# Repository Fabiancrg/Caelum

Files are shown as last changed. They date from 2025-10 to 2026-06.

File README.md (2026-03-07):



| Supported Target | ESP32-H2 |
| --- | --- |

# Caelum - Zigbee Weather Station




## Project Description

This project implements a battery-powered comprehensive weather station using ESP32-H2 with Zigbee connectivity. The device operates as a Zigbee Sleepy End Device (SED) with automatic light sleep for ultra-low power consumption while maintaining network responsiveness.

**Hardware v2.0** features dual I2C buses supporting multiple sensor combinations, dedicated rain gauge and anemometer inputs, DS18B20 temperature sensor, light sensor, and wind direction sensor for professional weather monitoring capabilities.

## Device Features

### 🌐 Zigbee Endpoints Overview (v2.0 Hardware)

| Endpoint | Device Type | Clusters | Description |
|---|---|---|---|
| **1** | Environmental Sensor | Temperature, Humidity, Pressure, Battery, OTA | Multi-sensor support via dual I2C buses |
| **2** | Rain Gauge | Analog Input | Tipping bucket rain sensor with rainfall totals (GPIO12) |
| **3** | DS18B20 Temperature | Temperature Measurement | External waterproof temperature probe (GPIO24) |
| **4** | Anemometer (Wind Speed) | Analog Input | Wind speed sensor with pulse counting (GPIO14) |
| **5** | Wind Direction | Analog Input | AS5600 magnetic wind vane (I2C Bus 2) |
| **6** | Light Sensor | Illuminance Measurement | VEML7700 ambient light sensor (I2C Bus 2) |

### 💡 LED Boot Indicator (Always Active)

The device includes a WS2812 RGB LED on GPIO8 (ESP32-H2) that provides visual feedback during boot and network join:
- **Yellow (Blinking)**: Joining/searching for network  
- **Blue (Steady, 5 seconds)**: Successfully connected to Zigbee network
- **Red (Blinking, 10 times)**: Connection failed after max retries
- **Off**: LED powered down after boot sequence (RMT peripheral disabled for power savings)

**Power Optimization**: The LED and its RMT peripheral are permanently disabled after the initial boot/join sequence to save ~1-2mA. This is critical for achieving 0.68mA sleep current. The LED cannot be re-enabled remotely - it only operates during the first boot cycle.

### 📋 Detailed Endpoint Descriptions (v2.0)

#### **Endpoint 1: Environmental Monitoring & Power Management**
- **I2C Bus 1 (GPIO10/11)**: Temperature, Humidity, Pressure sensors
- **Supported Sensors** (automatically detected):
  - **SHT41** (Bus 1): High-accuracy Temperature + Humidity (±0.2°C, ±1.8% RH)
  - **AHT20** (Bus 1): Alternative Temperature + Humidity sensor
  - **BMP280** (Bus 1): Temperature + Pressure (±1 hPa accuracy)
  - **BME280** (Bus 1): All-in-one Temperature + Humidity + Pressure
  - **DPS368** (Bus 1): High-precision Pressure sensor (±0.002 hPa)
- **Measurements**: 
  - 🌡️ **Temperature**: -40°C to +85°C (multiple sources available)
  - 💧 **Humidity**: 0-100% RH (from SHT41/AHT20/BME280)
  - 🌪️ **Pressure**: 300-1100 hPa (from BMP280/BME280/DPS368)
  - 🔋 **Battery Monitoring**: Li-Ion voltage (2.7V-4.2V) and percentage
- **Battery Monitoring**:
  - **Hardware**: GPIO4 (ADC1_CH4) with voltage divider
  - **MOSFET Control**: GPIO3 for active power management
  - **Voltage**: Real-time battery voltage in 0.1V units
  - **Percentage**: Battery level 0-100% based on Li-Ion discharge curve
  - **Calibration**: ESP32-H2 ADC correction factor (1.604x) for accurate readings
  - **Optimized Reading**: Time-based hourly intervals with NVS persistence

#### **Endpoint 2: Rain Gauge System**
- **Hardware**: Tipping bucket rain gauge with reed switch
  - **ESP32-H2 v2.0**: GPIO12 (interrupt-capable, dedicated rain input)
- **Measurements**: Cumulative rainfall in millimeters (0.36mm per tip)
- **Features**: 
  - Interrupt-based detection (200ms debounce)
  - Persistent storage (NVS) for total tracking
  - Smart reporting (1mm threshold increments)
  - Network-aware operation (ISR enabled only when connected)
  - Works during light sleep - wakes device on rain detection
- **Specifications**: 
  - Maximum rate: 200mm/hour supported
  - Accuracy: ±0.36mm per bucket tip
  - Storage: Non-volatile total persistence across reboots
- **Use Case**: Weather station, irrigation control, flood monitoring

#### **Endpoint 3: DS18B20 External Temperature Sensor**
- **Hardware**: DS18B20 1-Wire waterproof temperature probe
  - **GPIO24**: 1-Wire bus with parasitic power support
- **Measurements**: External temperature -55°C to +125°C (±0.5°C accuracy)
- **Features**:
  - Waterproof probe for outdoor/liquid temperature monitoring
  - 12-bit resolution (0.0625°C precision)
  - Independent from I2C environmental sensors
  - Parasitic power mode (no external power needed)
- **Use Case**: Soil temperature, water temperature, outdoor ambient temperature

#### **Endpoint 4: Anemometer (Wind Speed)**
- **Hardware**: Pulse-output anemometer
  - **GPIO14**: Interrupt-capable input for pulse counting
- **Measurements**: Wind speed via pulse frequency
- **Features**:
  - Interrupt-based pulse counting with debounce
  - Persistent storage (NVS) for total tracking
  - Similar architecture to rain gauge (proven reliability)
    
#### **Endpoint 5: Wind Direction**
- **Hardware**: AS5600 magnetic rotary position sensor (I2C Bus 2)
  - **I2C Address**: 0x36 (fixed)
  - **Resolution**: 12-bit (0.087° per step)
- **Measurements**: Wind direction 0-360° (compass bearing)
- **Features**:
  - Contactless magnetic sensing (no wear)
  - Absolute position (no homing required)
  - High resolution for accurate wind vane reading

#### **Endpoint 6: Light Sensor**
- **Hardware**: VEML7700 ambient light sensor (I2C Bus 2)
  - **I2C Address**: 0x10 (fixed)
  - **Range**: 0.0036 to 120,000 lux
- **Measurements**: Ambient light intensity in lux
- **Features**:
  - High dynamic range (16-bit resolution)
  - Automatic gain adjustment
  - Human eye response matching

### 🔧 Hardware Configuration

#### **Required Components (v2.0 Hardware)**
- ESP32-H2 development board (RISC-V architecture)
- **I2C Bus 1 Sensors** (Temperature/Humidity/Pressure):
  - **SHT41** - High-accuracy temperature + humidity (recommended)
  - **AHT20** - Alternative temperature + humidity sensor
  - **BMP280** - Pressure sensor (pairs with SHT41/AHT20)
  - **BME280** - All-in-one temp/humidity/pressure (alternative)
  - **DPS368** - High-precision barometric pressure sensor (optional, alternative to BMP280)
- **I2C Bus 2 Sensors** (Wind/Light/Pressure):
  - **AS5600** - Magnetic rotary position sensor for wind direction
  - **VEML7700** - Ambient light sensor (lux measurements)
- **1-Wire Sensor**:
  - **DS18B20** - Waterproof temperature probe for external measurements
- **Weather Sensors**:
  - Tipping bucket rain gauge with reed switch (0.36mm per tip)
  - Anemometer with pulse output for wind speed measurement
- **Power System**:
  - Li-Ion battery
  - Voltage divider
  - MOSFET for battery power management (GPIO3 control)
- Zigbee coordinator (ESP32-H2 or commercial gateway)

#### **Pin Assignments**

**ESP32-H2 (v2.0 Hardware)**
```
GPIO 1  - I2C Bus 2 SDA (AS5600 wind direction, VEML7700 light sensor, DPS368 pressure)
GPIO 2  - I2C Bus 2 SCL (AS5600 wind direction, VEML7700 light sensor, DPS368 pressure)
GPIO 3  - Battery MOSFET control (active power management)
GPIO 4  - Battery voltage input (ADC1_CH4 with voltage divider)
GPIO 8  - WS2812 RGB LED (debug indicator, optional)
GPIO 9  - Built-in button (factory reset)
GPIO 10 - I2C Bus 1 SDA (SHT41/AHT20 temp/humidity, BMP280/BME280 pressure)
GPIO 11 - I2C Bus 1 SCL (SHT41/AHT20 temp/humidity, BMP280/BME280 pressure)
GPIO 12 - Rain gauge input (tipping bucket with reed switch)
GPIO 14 - Anemometer input (wind speed pulse counter)
GPIO 24 - DS18B20 1-Wire temperature sensor (waterproof probe)
```

**Note**: v2.0 uses dedicated dual I2C buses to avoid address conflicts and support expanded sensor array.

### 🔌 Zigbee Integration
- **Protocol**: Zigbee 3.0  
- **Device Type**: Sleepy End Device (SED) - maintains network connection while sleeping
- **Sleep Mode**: Automatic light sleep with 7.5s keep-alive polling
- **Sleep Threshold**: 6.0 seconds (allows sleep between keep-alive polls)
- **Supported Channels**: 11-26 (2.4 GHz)
- **Compatible**: Zigbee2MQTT, Home Assistant ZHA, Hubitat
- **OTA Support**: Over-the-air firmware updates enabled (see [OTA_GUIDE.md](OTA_GUIDE.md))

### ⚡ Power Management (Light Sleep Mode)

**Zigbee Sleepy End Device (SED) Configuration**:
- **Keep-alive Polling**: 7.5 seconds (maintains parent connection)
- **Sleep Threshold**: 6.0 seconds (enters light sleep when idle)
- **Parent Timeout**: 64 minutes (how long parent keeps device in child table)
- **RX on When Idle**: Disabled (radio off during sleep for power savings)

**Power Consumption**:
- **Sleep Current**: **0.68mA** (with RMT peripheral powered down)
- **Transmit Current**: 12mA during active transmission
- **Average Current**: ~0.83mA (includes 7.5s polling cycles)
- **LED Power-down**: Critical for low power - RMT peripheral disabled after boot

**Sleep Behavior**:
- Device sleeps automatically when Zigbee stack is idle (no activity for 6 seconds)
- Wakes every 7.5 seconds to poll parent for pending messages
- Rain detection wakes device instantly via GPIO interrupt
- Quick response to Zigbee commands (<10 seconds typical)

**Power Optimization Features**:
- RMT peripheral (LED driver) powered down after boot sequence (~1-2mA savings)
- Light sleep maintains Zigbee network association (no rejoin delays)
- Automatic sleep/wake managed by ESP Zigbee stack
- Battery monitoring on 1-hour intervals with NVS persistence
- BME280 forced measurement mode (sensor sleeps between readings)

**Battery Life Estimate**:
- **2500mAh Li-Ion**: ~125 days (4+ months) at 0.83mA average
- **Breakdown**: 
  - ~7.4 seconds sleep per 7.5 second cycle (0.68mA)
  - ~0.1 seconds active per cycle (12mA transmit)
  - Sensor readings and reports as configured

**OTA Behavior**: 
- Device stays awake during firmware updates (`esp_zb_ota_is_active()` check)
- Normal sleep resumes after OTA completion

### � Zigbee Integration
- **Protocol**: Zigbee 3.0  
- **Device Type**: End Device (sleepy end device for battery operation)
- **Supported Channels**: 11-26 (2.4 GHz)
- **Compatible**: Zigbee2MQTT, Home Assistant ZHA
- **OTA Support**: Over-the-air firmware updates enabled (see [OTA_GUIDE.md](OTA_GUIDE.md))

## 🚀 Quick Start

### Prerequisites

```bash
# Install ESP-IDF v5.5.3 or later
git clone -b v5.5.3 --recursive https://github.com/espressif/esp-idf.git
cd esp-idf
# For ESP32-H2 (v2.0 hardware required)
./install.sh esp32h2
. ./export.sh
```

### Configure the Project
```bash
# For ESP32-H2 v2.0 hardware
idf.py set-target esp32h2
idf.py menuconfig
```

**Note**: v2.0 firmware requires v2.0 hardware (dual I2C buses, new GPIO assignments). For v1.0 hardware (ESP32-C6 or ESP32-H2 single I2C), use the `caelum-weatherstation` repository.

### Build and Flash
```bash
# Erase previous data (recommended for first flash)
idf.py -p [PORT] erase-flash

# Build and flash the project
idf.py -p [PORT] flash monitor
```

### 🛠️ Configuration

### Device Operation

#### **Factory Reset**
- **Built-in Button (GPIO 9)**:
  - Long press (5s): Factory reset device and rejoin network

#### **Automatic Features**
- **Light Sleep**: Automatic entry when idle (6s threshold, 7.5s keep-alive polling)
- **Sensor Reporting**: Environmental data reported after network join and on-demand
- **Rain Detection**: Interrupt-based instant wake and reporting (1mm threshold)
- **Battery Monitoring**: Hourly readings with time-based NVS persistence
- **Network Status**: Visual feedback via RGB LED during boot/join only
- **Power Savings**: RMT peripheral powered down after boot (~1-2mA savings)

### 📡 Data Reporting
- **Temperature/Humidity/Pressure**: Reported after network join and as configured
- **Rainfall**: Immediate on rain detection (1mm threshold)
- **Battery**: Hourly time-based readings with NVS persistence
- **Reporting Interval**: Configurable 60-7200 seconds via Endpoint 3
- **Response Time**: <10 seconds for Zigbee commands (7.5s keep-alive polling)

## 📊 Example Output

### Device Initialization (with Sensor Auto-Detection)
```
I (3668) i2c_bus: i2c0 bus inited
I (3670) i2c_bus: I2C Bus V2 Config Succeed, Version: 1.5.0
I (3686) i2c_bus: found i2c device address = 0x44
I (3695) i2c_bus: found i2c device address = 0x76
I (3696) SENSOR_IF: I2C scan: 2 device(s): 0x44 0x76
I (3697) SENSOR_IF: Probing for BME280...
W (3698) BME280_APP: ⚠ Detected BMP280 sensor (Chip ID: 0x58) - Temperature + Pressure ONLY (no humidity!)
I (3704) SENSOR_IF: BMP280 detected (no humidity), searching for separate humidity sensor...
I (3710) SHT41: sht41_init: device created successfully
I (3715) SENSOR_IF: Detected sensor combo: SHT41 + BMP280 (temp/RH from SHT41, pressure from BMP280)
I (3720) WEATHER_STATION: Detected SHT41 + BMP280 sensor combo on ESP32-H2 (SDA:GPIO10, SCL:GPIO11)
I (3730) RAIN_GAUGE: Rain gauge initialized. Current total: 0.00 mm
```

### Alternative Sensor Configurations
```
# BME280 all-in-one sensor
I (3697) SENSOR_IF: Probing for BME280...
I (3698) BME280_APP: ✓ Detected BME280 sensor (Chip ID: 0x60) - Temperature + Humidity + Pressure
I (3704) SENSOR_IF: Detected sensor: BME280
I (3710) WEATHER_STATION: Detected BME280 sensor on ESP32-H2 (SDA:GPIO10, SCL:GPIO11)

# SHT41 alone (no pressure sensor)
I (3697) SENSOR_IF: Probing for BME280...
I (3698) SENSOR_IF: BME280 not found, probing for SHT41 + BMP280 combo...
I (3704) SHT41: sht41_init: device created successfully
I (3710) SENSOR_IF: Detected sensor: SHT41 only (pressure will default to 1000.0 hPa)
I (3715) WEATHER_STATION: Detected SHT41 sensor on ESP32-H2 (SDA:GPIO10, SCL:GPIO11)
```

### Zigbee SED Configuration
```
I (600) WEATHER_STATION: 🔋 Configured as Sleepy End Device (SED) - rx_on_when_idle=false
I (610) WEATHER_STATION: 📡 Keep-alive poll interval: 7500 ms (7.5 sec)
I (620) WEATHER_STATION: 💤 Sleep threshold: 6000 ms (6.0 sec) - production optimized
I (630) WEATHER_STATION: ⏱️  Parent timeout: 64 minutes
I (640) WEATHER_STATION: ⚡ Power profile: 0.68mA sleep, 12mA transmit, ~0.83mA average
```

### Network Connection (LED Shows Status)
```
I (3558) WEATHER_STATION: Joined network successfully (Extended PAN ID: 74:4d:bd:ff:fe:63:f7:30, PAN ID: 0x13af, Channel:13, Short Address: 0x7c16)
I (3568) WEATHER_STATION: 💡 LED will power down in 5 seconds to save battery
I (3578) RAIN_GAUGE: Rain gauge enabled - device connected to Zigbee network
I (3588) WEATHER_STATION: 📊 Scheduling initial sensor data reporting after network join
I (8568) WEATHER_STATION: 🔌 RGB LED RMT peripheral powered down (boot sequence complete)
```

### Sensor Data Reporting
```
I (4000) WEATHER_STATION: 🌡️ Temperature: 22.35°C reported to Zigbee  
I (5010) WEATHER_STATION: 💧 Humidity: 45.20% reported to Zigbee
I (6020) WEATHER_STATION: 🌪️ Pressure: 1013.25 hPa reported to Zigbee
I (7030) BATTERY: 🔋 Li-Ion Battery: 4.17V (98%) - Zigbee values: 41 (0.1V), 196 (%*2)
I (8040) WEATHER_STATION: 📡 Temp: 22.4°C
I (8050) WEATHER_STATION: 📡 Humidity: 45.2%
I (8060) WEATHER_STATION: 📡 Pressure: 1013.3 hPa
```

### Rain Gauge Activity
```  
I (10000) RAIN_GAUGE: 🌧️ Rain pulse #1: 0.36 mm total (+0.36 mm)
I (10020) RAIN_GAUGE: ✅ Rain reported: 0.36 mm
I (10030) WEATHER_STATION: 📡 Rain: 0.36 mm
```

### Light Sleep Activity
```
I (15000) WEATHER_STATION: Zigbee can sleep
I (15010) WEATHER_STATION: 💤 Entering light sleep (will wake for 7.5s keep-alive poll)
```

## 🏠 Home Assistant Integration

When connected to Zigbee2MQTT or other Zigbee coordinators, the v2.0 device exposes:

- **6x Sensor entities**: 
  - Temperature (Environmental + DS18B20 external probe)
  - Humidity
  - Pressure  
  - Battery Percentage
  - Wind Speed
  - Wind Direction (0-360° compass bearing)
  - Light Level (lux)
- **2x Sensor entities**: 
  - Battery Voltage (mV)
  - Rainfall total (mm) with automatic updates
- **LED Control**: ⚠️ **Not available in v2.0** - LED operates only during boot/join sequence

### Endpoint Summary for Home Assistant

| Endpoint | Entity Type | Measurements | Update Frequency |
|---|---|---|---|
| 1 | Sensor | Temp, Humidity, Pressure, Battery | Configurable (default 15min) |
| 2 | Sensor | Rainfall total (mm) | On rain detection (1mm threshold) |
| 3 | Sensor | External temperature (DS18B20) | Configurable (default 15min) |
| 4 | Sensor | Wind speed | Configurable (default 15min) |
| 5 | Sensor | Wind direction (0-360°) | Configurable (default 15min) |
| 6 | Sensor | Light level (lux) | Configurable (default 15min) |

### Zigbee2MQTT Integration

A custom external converter is provided for full feature support with Zigbee2MQTT. See [ZIGBEE2MQTT_CONVERTER.md](ZIGBEE2MQTT_CONVERTER.md) for:
- Converter installation instructions
- Multi-endpoint support configuration
- v2.0 endpoint mappings (6 endpoints)
- Home Assistant automation examples

**Note**: v2.0 requires updated converter due to new endpoint structure (6 endpoints vs 4 in v1.0)

## 🔄 Migration Guide: v1.0 → v2.0

### Hardware Requirements
⚠️ **v2.0 firmware requires v2.0 hardware** - GPIO assignments are completely different.

| Component | v1.0 | v2.0 | Compatible? |
|---|---|---|---|
| Target | ESP32-H2 or C6 | ESP32-H2 only | ❌ Different GPIO |
| I2C Bus | Single (GPIO10/11) | Dual (GPIO10/11 + GPIO1/2) | ⚠️ Partial |
| Rain Gauge | GPIO12 (H2), GPIO5 (C6) | GPIO12 only | ✅ H2 compatible |
| Pulse Counter | GPIO13 | Removed | ❌ Deprecated |
| Anemometer | N/A | GPIO14 | ➕ New |
| DS18B20 | N/A | GPIO24 | ➕ New |
| Battery MOSFET | N/A | GPIO3 | ➕ New |

## 🔄 OTA Updates

This project supports Over-The-Air (OTA) firmware updates via Zigbee network. See [OTA_GUIDE.md](OTA_GUIDE.md) for detailed instructions on:
- Creating OTA images
- Configuring Zigbee2MQTT for OTA
- Performing updates
- Troubleshooting OTA issues

## 📄 License

This project follows dual licensing:
- **Software**: GNU General Public License v3.0 (see [LICENSE](LICENSE))
- **Hardware**: Creative Commons Attribution-NonCommercial-ShareAlike 4.0 (see [LICENSE-hardware](LICENSE-hardware))

## 🤝 Contributing

Contributions are welcome! Please feel free to submit issues or pull requests.

For technical queries, please open an issue on GitHub. Include:
- Complete serial monitor output
- Hardware configuration details  
- ESP-IDF and SDK versions
- Specific symptoms and reproduction steps

## 💖 Support

If you find this project useful, consider supporting the development:



---

**Project**: Caelum - ESP32 Zigbee Weather Station  
**Version**: v2.0 - Hardware redesign with dual I2C buses and expanded sensor array  
**Compatible**: ESP32-H2 (v2.0), ESP32-C6 (v1.0 legacy), ESP-IDF v5.5.3+  
**License**: GPL v3 (Software) / CC BY-NC-SA 4.0 (Hardware)  
**Features**: 
- 6-endpoint design (ENV, RAIN, DS18B20, WIND_SPEED, WIND_DIR, LIGHT)
- Dual I2C buses for expanded sensor support without address conflicts
- Professional weather monitoring (temperature, humidity, pressure, rain, wind, light)
- DS18B20 waterproof external temperature probe
- AS5600 magnetic wind direction sensor (0-360°)
- VEML7700 ambient light sensor (0.0036-120k lux)
- Anemometer wind speed measurement
- OTA firmware updates
- Optimized battery monitoring with hourly time-based intervals
- WS2812 RGB LED status indicator during boot/join
- Ultra-low power: 0.68mA sleep current for extended battery life

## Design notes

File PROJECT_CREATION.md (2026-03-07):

# WeatherStation Project Creation Summary

## Overview
Successfully created a new **WeatherStation** project based on the **ZigbeeMultiSensor** project.

## Project Location
```
c:\Devel\Repositories\WeatherStation
```

## What Was Done

### 1. Project Structure Copied
All essential files and directories were copied from ZigbeeMultiSensor:
- ✅ Source code (`main/` directory with all .c and .h files)
- ✅ Build configuration (`CMakeLists.txt`, `sdkconfig`, `sdkconfig.defaults`)
- ✅ Development tools (`.vscode/`, `.devcontainer/`, `.clangd`)
- ✅ Project metadata (`.gitignore`, `partitions.csv`)

### 2. Excluded Items (Clean Copy)
The following were intentionally excluded:
- ❌ `.git/` - No git history (fresh start)
- ❌ `build/` - Build artifacts (will be regenerated)
- ❌ `managed_components/` - Will be downloaded on first build
- ❌ `dependencies.lock` - Will be regenerated
- ❌ Build logs and temporary files

### 3. Project Renamed
- **CMakeLists.txt**: Project name changed from `zigbeeTest` to `WeatherStation`
- **README.md**: Completely rewritten for weather station focus

## Project Features (Inherited from ZigbeeMultiSensor)

### Hardware Support
- **MCU**: ESP32-C6 or ESP32-H2
- **Zigbee**: Full Zigbee 3.0 stack with 5 endpoints

### Endpoints Configuration
1. **Endpoint 1**: LED Strip (WS2812B on GPIO 8)
2. **Endpoint 2**: GPIO LED (GPIO 0)
3. **Endpoint 3**: Button Sensor (GPIO 12)
4. **Endpoint 4**: BME280 Environmental Sensor (I2C on GPIO 6/7)
5. **Endpoint 5**: Rain Gauge (GPIO 18)

### Source Files Included
```
main/
├── bme280_app.c         # BME280 sensor driver
├── bme280_app.h         # BME280 interface
├── esp_zb_light.c       # Main Zigbee stack (49KB)
├── esp_zb_light.h       # Configuration headers
├── light_driver.c       # LED/GPIO control (19KB)
├── light_driver.h       # Driver interface
├── CMakeLists.txt       # Component config
└── idf_component.yml    # Dependencies
```

## Next Steps

### 1. Initialize Git (Optional)
```bash
cd c:\Devel\Repositories\WeatherStation
git init
git add .
git commit -m "Initial commit - Weather Station project based on ZigbeeMultiSensor"
```

### 2. Build the Project
```bash
cd c:\Devel\Repositories\WeatherStation

# Set target (if not already set)
idf.py set-target esp32c6

# Build
idf.py build
```

### 3. Flash to Device
```bash
# Erase flash (recommended for first flash)
idf.py erase-flash

# Flash and monitor
idf.py -p COM_PORT flash monitor
```

### 4. Customization Ideas
Consider modifying for weather station specific features:
- Add weather trend calculation (pressure changes)
- Implement data logging to flash
- Add wind speed/direction sensors
- Customize LED patterns for weather alerts
- Add battery monitoring for solar power

## Configuration Files

### Key Settings in `sdkconfig`
- Zigbee role: End Device (can be changed to Router)
- I2C configuration for BME280
- GPIO assignments for sensors and LEDs

### Component Dependencies (`main/idf_component.yml`)
- LED strip driver
- BME280 sensor library
- ESP-Zigbee libraries

## Differences from Original

| Aspect | ZigbeeMultiSensor | WeatherStation |
|---|---|---|
| Project Name | `zigbeeTest` | `WeatherStation` |
| README | Multi-sensor focus | Weather station focus |
| Git History | Preserved | Fresh start (no .git) |
| Build Artifacts | May exist | Clean (excluded) |

## Testing Checklist

Before first use, verify:
- [ ] ESP-IDF environment is set up (v5.5.3+)
- [ ] ESP32-C6 or ESP32-H2 hardware available
- [ ] BME280 sensor connected to I2C (GPIO 6/7)
- [ ] USB cable and COM port identified
- [ ] Zigbee coordinator running (Zigbee2MQTT or ZHA)

## Support

This project inherits all features from ZigbeeMultiSensor and is optimized for weather monitoring applications.

For issues or contributions, refer to the main README.md in the project directory.

---
**Created**: October 16, 2025
**Based on**: ZigbeeMultiSensor by Fabiancrg
**Status**: Ready to build and flash

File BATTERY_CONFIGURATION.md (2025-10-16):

# ESP32-H2 Battery-Powered Weather Station Guide

## Overview
This guide explains how to configure the ESP32-H2 Weather Station for battery-powered operation with deep sleep mode.

## Battery Requirements

### Recommended Battery Options

#### Option 1: 18650 Li-ion Battery (Recommended)
- **Voltage**: 3.7V nominal (3.0V - 4.2V range)
- **Capacity**: 2500-3500 mAh
- **Runtime**: 6-12 months (depending on reporting frequency)
- **Advantages**: High capacity, rechargeable, widely available
- **Cost**: $5-10 per cell

#### Option 2: 3x AA/AAA Batteries
- **Voltage**: 3x 1.5V = 4.5V nominal
- **Capacity**: 2000-3000 mAh (AA), 800-1200 mAh (AAA)
- **Runtime**: 3-6 months
- **Advantages**: Easy to replace, no special charger needed
- **Cost**: $2-5 per set

#### Option 3: LiPo Battery Pack
- **Voltage**: 3.7V (1S LiPo)
- **Capacity**: 2000-5000 mAh
- **Runtime**: 6-18 months
- **Advantages**: Lightweight, various form factors
- **Cost**: $10-20

### Battery Connection

```
ESP32-H2 Pin Configuration:
┌────────────────────┐
│     ESP32-H2       │
│                    │
│  3V3  ──┬──────────┼──── Battery + (via regulator if >3.6V)
│         │          │
│       [100µF]      │     Optional: Add 100µF capacitor
│         │          │     near power pins for stability
│  GND  ──┴──────────┼──── Battery -
│                    │
│  GPIO18 ────────────┼──── Rain Sensor (wake-up pin)
│                    │
└────────────────────┘
```

### Hardware Setup

1. **With Li-ion/LiPo (3.7V)**:
   ```
   Battery (+) ──> [TP4056 Charger] ──> [LDO 3.3V] ──> ESP32-H2 (3V3)
   Battery (-) ────────────────────────────────────> ESP32-H2 (GND)
   ```

2. **With 3x AA/AAA (4.5V)**:
   ```
   Batteries (+) ──> [AMS1117-3.3 LDO] ──> ESP32-H2 (3V3)
   Batteries (-) ─────────────────────> ESP32-H2 (GND)
   ```

## Power Consumption Analysis

### Active Mode (Zigbee TX/RX)
- **Current Draw**: 15-25 mA
- **Duration**: 2-5 seconds per wake cycle
- **Energy**: ~0.02 mAh per cycle

### Deep Sleep Mode
- **Current Draw**: 7-10 µA (microamps!)
- **Duration**: 15 minutes (900 seconds)
- **Energy**: ~0.002 mAh per cycle

### Daily Energy Calculation (15-minute intervals)
```
Wake cycles per day: 96 (24h * 4 per hour)
Active energy: 96 * 0.02 mAh = 1.92 mAh/day
Sleep energy: 96 * 0.002 mAh = 0.19 mAh/day
Total: ~2.1 mAh/day
```

### Battery Life Estimates
- **2500 mAh battery**: 2500 / 2.1 ≈ **1190 days** (~3.3 years!)
- **3000 mAh battery**: 3000 / 2.1 ≈ **1428 days** (~3.9 years!)

*Note: Actual battery life depends on self-discharge rate (~2-5% per month for Li-ion) and rain events.*

### With Rain Events
If it rains 10 times per day with 1mm+ rainfall:
```
Additional wake cycles: 10
Additional energy: 10 * 0.02 mAh = 0.2 mAh/day
New total: ~2.3 mAh/day
Battery life: still >3 years with 2500mAh battery
```

## Deep Sleep Configuration

### Wake-up Triggers

1. **Timer Wake-up (Every 15 minutes)**
   - Report temperature, humidity, pressure
   - Report rainfall total
   - Check for coordinator messages

2. **GPIO Wake-up (Rain detection)**
   - GPIO18 (rain gauge tipping bucket)
   - Wake immediately when rain detected
   - Report rainfall increment

### Sleep Mode Details

```c
// Deep sleep power domains
- RTC memory: ACTIVE (stores rainfall counter)
- RTC slow clock: ACTIVE (for wake timer)
- RTC fast memory: OFF
- Wi-Fi/Bluetooth: OFF
- Digital peripherals: OFF
- I2C: OFF (powered down)
- UART: OFF (powered down)
```

## Code Changes Made

### 1. Changed Device Type
```c
// OLD: Mains-powered End Device
#define ESP_ZB_ZED_CONFIG() ...

// NEW: Battery-powered Sleepy End Device  
#define ESP_ZB_SED_CONFIG() {
    .esp_zb_role = ESP_ZB_DEVICE_TYPE_ED,
    .install_code_policy = false,
    .nwk_cfg.zed_cfg = {
        .ed_timeout = ESP_ZB_ED_AGING_TIMEOUT_8MIN,
        .keep_alive = 15000, // 15 seconds
    },
}
```

### 2. Added Deep Sleep Functions
- `enter_deep_sleep()` - Configures and enters deep sleep
- `check_wake_reason()` - Determines why device woke up
- `handle_timer_wakeup()` - Processes periodic wake-ups
- `handle_rain_wakeup()` - Processes rain-triggered wake-ups

### 3. Modified Main Loop
- Removed infinite Zigbee loop
- Added sleep cycle after reporting
- Saves state to RTC memory

### 4. Updated Rain Gauge
- Rain detection triggers immediate wake-up
- Pulse count stored in RTC memory (survives sleep)
- Reports rainfall on wake-up

## Configuration Options

### Adjust Sleep Duration
Edit `esp_zb_weather.h`:
```c
#define SLEEP_DURATION_MINUTES  15    // Change to 10, 20, 30, etc.
#define SLEEP_DURATION_S  (SLEEP_DURATION_MINUTES * 60)
```

### Adjust Rain Threshold
```c
#define RAIN_MM_PER_PULSE  0.2794f  // Standard tipping bucket
```

### Battery Voltage Monitoring (Optional)
```c
// Add ADC code to monitor battery voltage
// Warn when battery < 3.0V for Li-ion
// Warn when battery < 3.6V for 3xAA
```

## Testing & Debugging

### Test Deep Sleep
```bash
# Monitor serial output
idf.py monitor

# You should see:
# - Device wakes up every 15 minutes
# - Reports sensor data
# - Enters deep sleep
# - Wake-up reason logged
```

### Test Rain Wake-up
```bash
# Manually trigger GPIO18 high
# Device should wake immediately
# Report rain increment
# Return to sleep
```

### Measure Current Draw
Use a multimeter in series with battery:
- Active: 15-25 mA
- Sleep: <10 µA

## LED Behavior

### Power Saving Modifications
- LED strip disabled in battery mode (saves power)
- Status LED blinks briefly on wake-up
- No continuous LEDs during sleep

## Zigbee Network Considerations

### Poll Rate
- Sleepy End Devices poll parent every 7.5 seconds while awake
- Coordinator buffers messages for sleeping devices
- Device must wake up to receive commands

### Parent Device
- **Must be connected to a Zigbee Router or Coordinator**
- Routers keep track of sleeping children
- Messages are queued until device wakes up

### Limitations
- **Cannot receive instant commands** during sleep
- Commands take effect on next wake-up (max 15 min delay)
- Coordinator must support Sleepy End Devices

## Troubleshooting

### Device doesn't wake up
- Check battery voltage (>3.0V for Li-ion)
- Verify GPIO18 connection
- Check RTC clock crystal (if external)

### Short battery life
- Verify deep sleep current (<10µA)
- Disable LED strip in code
- Increase sleep duration
- Check for wake-up loops

### Lost network connection
- Increase `ed_timeout` in config
- Reduce sleep duration
- Ensure coordinator supports long poll intervals

## Bill of Materials (BOM)

### Minimal Setup
| Component | Part Number | Qty | Cost |
|---|---|-----|---|
| ESP32-H2 DevKit | ESP32-H2-DevKitM-1 | 1 | $10 |
| 18650 Battery | Any 3.7V Li-ion | 1 | $6 |
| TP4056 Charger | TP4056 Module | 1 | $1 |
| AMS1117-3.3 | LDO Regulator | 1 | $0.50 |
| BME280 Sensor | BME280 I2C Module | 1 | $5 |
| Rain Gauge | Tipping Bucket | 1 | $15 |
| **Total** | | | **~$37** |

### Recommended Setup (with PCB)
Add:
- Custom PCB ($5)
- Battery holder ($2)
- Connector headers ($1)
- Protection circuitry ($2)
- **Total: ~$47**

## Next Steps

1. ✅ Flash the updated firmware
2. ✅ Connect battery with proper voltage regulation
3. ✅ Test wake-up behavior
4. ✅ Monitor current consumption
5. ✅ Pair with Zigbee coordinator
6. ✅ Verify 15-minute reporting
7. ✅ Test rain detection wake-up
8. ✅ Calculate actual battery life

---
**Important**: Always use proper voltage regulation. Direct connection of >3.6V to ESP32-H2 will damage the chip!

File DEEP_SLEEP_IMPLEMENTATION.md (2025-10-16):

# Deep Sleep Implementation Summary

## Changes Made for Battery Operation

### Files Created
1. **`sleep_manager.c`** - Deep sleep management implementation
2. **`sleep_manager.h`** - Sleep manager header file  
3. **`BATTERY_CONFIGURATION.md`** - Comprehensive battery guide

### Files Modified
1. **`esp_zb_weather.h`**
   - Changed `ED_AGING_TIMEOUT` from 64 minutes to 8 minutes (sleepy device)
   - Changed `ED_KEEP_ALIVE` from 3 seconds to 15 seconds (longer poll interval)
   - Added deep sleep configuration defines:
     - `SLEEP_DURATION_MINUTES` = 15
     - `RAIN_WAKE_GPIO` = GPIO 18
     - `RAIN_MM_THRESHOLD` = 1.0mm

2. **`esp_zb_weather.c`**
   - Added `#include "sleep_manager.h"`
   - Updated file header comments (battery-powered station)
   - Modified `app_main()` to:
     - Check wake-up reason on boot
     - Load rainfall data from RTC/NVS
     - Print battery statistics
   - Modified `esp_zb_task()` to:
     - Run limited Zigbee operations (10 seconds)
     - Enter deep sleep after reporting
     - Enable GPIO wake-up for rain detection

### Key Architecture Changes

#### Before (Mains-Powered)
```
Boot → Initialize → Join Network → Infinite Loop
                                      ↓
                                  Poll sensors
                                  Report data
                                  Handle events
                                      ↑
                                      └──── Forever
```

#### After (Battery-Powered)
```
Boot → Check Wake Reason → Load State → Initialize
   ↓
Join Network (if needed)
   ↓
Run for 10 seconds (report sensors, handle events)
   ↓
Save State → Enter Deep Sleep (15 min OR rain event)
   ↓
Wake Up ────┘
```

## Power Savings Achieved

### Current Draw Comparison
| Mode | Before (Mains) | After (Battery) | Savings |
|---|---|---|---|
| **Active** | 20-25 mA continuous | 20-25 mA for 10s | N/A |
| **Idle** | 20-25 mA continuous | 7-10 µA sleep | **99.96%** |
| **Daily Energy** | 480-600 mAh | ~2.1 mAh | **99.6%** |

### Battery Life Estimates
- **2500 mAh battery**: ~3.3 years
- **3000 mAh battery**: ~3.9 years  
- **5000 mAh battery**: ~6.5 years

## Wake-Up Mechanisms

### 1. Timer Wake-Up (Every 15 Minutes)
```c
esp_sleep_enable_timer_wakeup(15 * 60 * 1000000ULL);
```
**Purpose**: Periodic sensor readings and reporting
- Temperature, humidity, pressure from BME280
- Rainfall total from RTC memory
- Network maintenance (rejoin if disconnected)

### 2. GPIO Wake-Up (Rain Detection)
```c
esp_sleep_enable_ext1_wakeup((1ULL << GPIO_18), ESP_EXT1_WAKEUP_ANY_HIGH);
```
**Purpose**: Immediate response to rainfall >1mm
- Wake on rising edge (bucket tip)
- Increment rain counter in RTC memory
- Report new rainfall total
- Return to sleep

### 3. Adaptive Sleep Duration
```c
// Heavy rain: check every 5 minutes
// Normal: check every 15 minutes
uint32_t sleep_duration = get_adaptive_sleep_duration(recent_rainfall_mm);
```

## Data Persistence

### RTC Memory (Fast, Volatile across power loss)
```c
static RTC_DATA_ATTR uint32_t boot_count = 0;
static RTC_DATA_ATTR float rtc_rainfall_mm = 0.0f;
static RTC_DATA_ATTR uint32_t rtc_rain_pulse_count = 0;
```
- Survives deep sleep
- Lost on power cycle
- Ultra-low power retention

### NVS Storage (Slow, Non-volatile)
```c
nvs_set_blob(nvs_handle, "rainfall", &rainfall_mm, sizeof(float));
nvs_set_u32(nvs_handle, "pulses", pulse_count);
```
- Survives power loss
- Backed up every 10 rain pulses
- Loaded on first boot after power loss

## Zigbee Configuration Changes

### Device Type
```c
// Remains as End Device (ED) but with sleepy parameters
.esp_zb_role = ESP_ZB_DEVICE_TYPE_ED
```

### Polling Parameters
```c
.ed_timeout = ESP_ZB_ED_AGING_TIMEOUT_8MIN  // Parent waits 8 min before dropping
.keep_alive = 15000  // Poll parent every 15 seconds while awake
```

### Network Behavior
- Device sends "End Device Timeout Request" to parent
- Parent (router/coordinator) buffers messages for up to 8 minutes
- Device polls parent on wake-up to retrieve buffered messages
- Automatic rejoin if network lost during sleep

## Testing Checklist

### Hardware Tests
- [ ] Measure active current (should be 20-25 mA)
- [ ] Measure sleep current (should be <10 µA)
- [ ] Test battery voltage monitoring
- [ ] Verify rain sensor triggers wake-up
- [ ] Test button wake-up (if implemented)

### Software Tests
- [ ] Verify 15-minute wake intervals
- [ ] Confirm sensor data reported correctly
- [ ] Test rainfall counter persistence (RTC + NVS)
- [ ] Verify wake reason logging
- [ ] Test network rejoin after long sleep
- [ ] Confirm coordinator buffers messages

### Network Tests
- [ ] Pair device with coordinator
- [ ] Verify device shows as "Sleepy End Device"
- [ ] Test delayed command response (max 15 min)
- [ ] Verify automatic rejoin after network loss
- [ ] Check LQI/RSSI values after wake-up

## Build Instructions

```bash
cd c:\Devel\Repositories\WeatherStation

# Clean previous build
idf.py fullclean

# Set target (ESP32-H2 for battery operation)
idf.py set-target esp32h2

# Configure (verify ZB_ED_ROLE is set)
idf.py menuconfig
# → Zigbee → Device Role → End Device

# Build
idf.py build

# Flash
idf.py -p COM_PORT flash

# Monitor
idf.py -p COM_PORT monitor
```

## Expected Serial Output

```
========================================
📊 WAKE-UP STATISTICS
========================================
Boot count: 1
Rainfall (RTC): 0.00 mm
Pulse count (RTC): 0
Duty cycle: ~0.3% (awake ~3s per 15min)
Sleep efficiency: ~99.7%
========================================
🔋 Battery capacity: 2500 mAh
📊 Daily consumption: 2.10 mAh
📅 Estimated battery life: 1190 days (~3.3 years)
🚀 Starting Zigbee Weather Station (Battery Mode)
Wake reason: RESET
...
⏳ Running Zigbee operations for 10 seconds...
🌡️ Temperature: 22.50°C reported to Zigbee
💧 Humidity: 45.20% reported to Zigbee
🌪️  Pressure: 1013.25 hPa reported to Zigbee
✅ Zigbee operations complete
💤 Entering deep sleep for 900 seconds (15 minutes)...
========================================
```

## Troubleshooting

### Issue: Device doesn't wake up
**Solutions**:
- Check battery voltage (must be >3.0V)
- Verify deep sleep enable calls succeeded
- Check RTC clock source configuration

### Issue: High sleep current (>50µA)
**Solutions**:
- Disable LED strip before sleep
- Verify I2C pullups disabled
- Check for floating GPIO pins
- Measure with multimeter in series

### Issue: Network connection lost
**Solutions**:
- Increase `ed_timeout` to 16 minutes
- Verify coordinator supports sleepy devices
- Check Zigbee channel stability
- Reduce sleep duration to 10 minutes

### Issue: Rainfall counter resets
**Solutions**:
- Verify NVS writes succeed (check logs)
- Ensure battery voltage stable during sleep/wake
- Check RTC memory retention
- Add more frequent NVS saves

## Future Enhancements

### Possible Improvements
1. **Battery Voltage Monitoring**
   ```c
   // Add ADC code to read battery voltage
   // Warn when <3.0V for Li-ion
   // Include in periodic reports
   ```

2. **Solar Panel Support**
   - Charge controller integration
   - Daytime active periods (1-min intervals)
   - Nighttime deep sleep (30-min intervals)

3. **OTA Updates via Zigbee**
   - Wake on coordinator request
   - Stay awake for firmware update
   - Resume normal sleep after update

4. **Wind Speed Sensor**
   - Additional GPIO interrupt
   - Pulse counting in RTC memory
   - Report on wake-up

5. **Adaptive Polling**
   - 5-min intervals during active weather
   - 30-min intervals during calm periods
   - Extend battery life in stable conditions

---
**Status**: ✅ Deep sleep implementation complete and ready for testing
**Next Step**: Flash firmware and measure actual current consumption

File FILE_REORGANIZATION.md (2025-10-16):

# File Reorganization Summary - WeatherStation Project

## Date: October 16, 2025

## Changes Made

Successfully reorganized the main source files to use weather-appropriate naming conventions instead of generic "light" naming.

### File Renames

| Old Filename | New Filename | Purpose |
|---|---|---|
| `esp_zb_light.c` | `esp_zb_weather.c` | Main Zigbee weather station implementation (1011 lines) |
| `esp_zb_light.h` | `esp_zb_weather.h` | Weather station header with endpoint definitions |
| `light_driver.c` | `weather_driver.c` | Driver for LEDs, GPIO, buttons, and sensors (460 lines) |
| `light_driver.h` | `weather_driver.h` | Driver interface definitions |

### Files Unchanged

These files retained their original names as they are sensor-specific:
- `bme280_app.c` - BME280 sensor application code
- `bme280_app.h` - BME280 sensor interface
- `CMakeLists.txt` - Component build configuration
- `idf_component.yml` - Component dependencies

## Code Updates

### Include Statement Changes

#### In `esp_zb_weather.c` (line 21):
```c
// OLD: #include "esp_zb_light.h"
// NEW: #include "esp_zb_weather.h"
```

#### In `esp_zb_weather.h` (line 16):
```c
// OLD: #include "light_driver.h"
// NEW: #include "weather_driver.h"
```

#### In `weather_driver.c` (line 40):
```c
// OLD: #include "light_driver.h"
// NEW: #include "weather_driver.h"
```

## Function Names - No Changes Required

The following function names remain unchanged (they are part of the public API):
- `light_driver_init()` - Initialize LED strip and GPIO LED
- `light_driver_set_power()` - Control LED strip power
- `light_driver_set_gpio_power()` - Control GPIO LED power
- `light_driver_get_power()` - Get LED strip state
- `external_button_driver_init()` - Initialize button with callback

**Rationale**: While the files are renamed, the LED functionality remains valid for a weather station (status indicators). Function names can be refactored in a future update if needed.

## Current Project Structure

```
WeatherStation/
├── main/
│   ├── esp_zb_weather.c      ✅ RENAMED (was esp_zb_light.c)
│   ├── esp_zb_weather.h      ✅ RENAMED (was esp_zb_light.h)
│   ├── weather_driver.c      ✅ RENAMED (was light_driver.c)
│   ├── weather_driver.h      ✅ RENAMED (was light_driver.h)
│   ├── bme280_app.c          ⚪ UNCHANGED
│   ├── bme280_app.h          ⚪ UNCHANGED
│   ├── CMakeLists.txt        ⚪ UNCHANGED
│   └── idf_component.yml     ⚪ UNCHANGED
├── CMakeLists.txt
├── sdkconfig
├── sdkconfig.defaults
├── partitions.csv
├── README.md
└── PROJECT_CREATION.md
```

## Build Verification

The project should build without issues as:
- ✅ All include statements updated
- ✅ No header guard changes needed (using `#pragma once`)
- ✅ Function implementations unchanged
- ✅ CMakeLists.txt uses wildcard includes (automatically picks up renamed files)

## Next Steps

### Ready to Build
```bash
cd c:\Devel\Repositories\WeatherStation
idf.py build
```

### Optional Future Enhancements
Consider renaming the driver functions in a future update:
- `light_driver_*()` → `weather_led_*()` or `status_led_*()`
- Add weather-specific driver functions:
  - `weather_get_temperature()`
  - `weather_get_humidity()`
  - `weather_get_pressure()`
  - `weather_get_rainfall()`

## Notes

- All file renames completed successfully
- All include references updated
- No compilation errors expected
- Code functionality preserved
- Project structure now clearly indicates weather station purpose

---
**Status**: ✅ **COMPLETE** - All files renamed and references updated successfully.

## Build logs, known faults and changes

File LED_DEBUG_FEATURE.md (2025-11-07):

# LED Debug Feature Documentation

## Overview

The Caelum Weather Station includes an LED debug feature that provides visual feedback about the device's operational state. This feature is controllable via Zigbee using endpoint 4.

## Hardware

- **LED Type**: WS2812 RGB LED (on ESP32-H2 SuperMini)
- **GPIO**: GPIO8
- **Driver**: espressif/led_strip ~2.0.0

## LED States

The LED displays different colors and patterns to indicate device status:

| State | Color | Pattern | Meaning |
|---|---|---|---|
| **Disconnected** | Orange | Blinking (500ms) | Device is joining/searching for Zigbee network |
| **Connected** | Blue | Steady | Device is connected to Zigbee network |
| **Rain Detection** | White | Brief flash (100ms) | Rain gauge pulse detected |
| **Sleeping** | Off | - | Device is in deep sleep mode |
| **Disabled** | Off | - | LED debug feature disabled via Zigbee |

## Zigbee Control

### Endpoint 4: LED Debug Control

The LED debug feature can be enabled/disabled remotely via Zigbee using endpoint 4:

- **Cluster**: genOnOff (0x0006)
- **Attribute**: onOff (0x0000)
- **Device Type**: On/Off Output (0x0002)
- **Default State**: Enabled (ON)

### Usage in Zigbee2MQTT

After pairing the device with Zigbee2MQTT, a switch entity will appear for "LED Debug":

```javascript
// In Z2M frontend:
// Switch: "LED Debug" - Toggle to enable/disable LED indicator

// Via MQTT:
mosquitto_pub -t 'zigbee2mqtt/caelum-weather-station/set' -m '{"state_4":"ON"}'   // Enable LED
mosquitto_pub -t 'zigbee2mqtt/caelum-weather-station/set' -m '{"state_4":"OFF"}'  // Disable LED
```

## Implementation Details

### Code Structure

**Files Modified:**
- `main/esp_zb_weather.h` - Added endpoint 4 definition and LED configuration
- `main/esp_zb_weather.c` - Implemented LED control functions and Zigbee endpoint
- `caelum-weather-station.js` - Added endpoint 4 to Z2M converter

**Key Components:**

1. **Control Variable** (`esp_zb_weather.c`):
   ```c
   static bool led_debug_enabled = true;  // Default: enabled
   ```

2. **LED Functions**:
   - `debug_led_init()` - Initialize WS2812 LED on GPIO8
   - `debug_led_set(bool state)` - Set LED on/off (respects led_debug_enabled)
   - `debug_led_start_blink()` - Start orange blinking for network joining
   - `debug_led_stop_blink()` - Stop blinking
   - `debug_led_rain_flash()` - White flash on rain detection

3. **Zigbee Attribute Handler**:
   ```c
   // Handles genOnOff writes on endpoint 4
   // Updates led_debug_enabled and immediately applies state
   ```

4. **Endpoint Configuration**:
   ```c
   esp_zb_endpoint_config_t endpoint_led_config = {
   /* LED debug endpoint removed; On/Off moved to primary endpoint (EP1) */
       .app_profile_id = ESP_ZB_AF_HA_PROFILE_ID,
       .app_device_id = ESP_ZB_HA_ON_OFF_OUTPUT_DEVICE_ID,
   };
   ```

### Behavior

**When Enabled (ON)**:
- LED shows network status (orange blink → blue solid)
- White flash on rain gauge pulses
- Turns off during deep sleep

**When Disabled (OFF)**:
- LED immediately turns off
- All LED functions skip execution
- Rain pulse detection continues (no visual feedback)
- Network operation unaffected

### Power Considerations

The LED debug feature has minimal impact on battery life:
- Only active during wake periods (~10-60 seconds)
- Off during deep sleep (majority of time)
- RGB LED draws ~20mA when on
- Can be disabled remotely to conserve battery in production deployments

## Configuration Options

Compile-time options in `esp_zb_weather.h`:

```c
#define DEBUG_LED_ENABLE 1          // Enable LED debug feature
#define DEBUG_LED_TYPE_RGB 1        // Use WS2812 RGB LED (0 = simple GPIO)
#define DEBUG_LED_GPIO GPIO_NUM_8   // GPIO pin for LED
```

For simple GPIO LED instead of WS2812:
```c
#define DEBUG_LED_TYPE_RGB 0        // Use simple GPIO LED
```

## Troubleshooting

**LED stays off**:
- Check if feature is enabled via Zigbee (endpoint 4 state)
- Verify DEBUG_LED_ENABLE=1 in esp_zb_weather.h
- Check GPIO8 connection to WS2812 LED
- Monitor logs for initialization errors

**LED doesn't flash on rain**:
- Verify rain gauge GPIO (default GPIO4) is connected
- Check Z2M for rainfall updates
- LED must be enabled and device must be awake

**Wrong colors**:
- Verify WS2812 LED type (not WS2811 or similar)
- Check led_strip component version (~2.0.0)
- Verify RMT channel configuration

## Future Enhancements

Potential improvements:
- NVS persistence for led_debug_enabled state
- Configurable LED brightness via Zigbee
- Additional color patterns for different events
- Low battery warning (red blink)

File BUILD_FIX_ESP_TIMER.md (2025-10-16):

# Build Fix: Removed esp_timer.h Dependency

## Issue
Compilation error in `sleep_manager.c`:
```
fatal error: esp_timer.h: No such file or directory
```

## Root Cause
The `esp_timer.h` header was included but:
1. Not actually used in the code
2. May not be available or properly configured for ESP32-H2 target
3. Was an unnecessary dependency

## Solution
Removed the unnecessary `esp_timer.h` include and added required FreeRTOS headers instead.

### Changes Made

**File: `main/sleep_manager.c`**

```diff
- #include "esp_timer.h"
+ #include "freertos/FreeRTOS.h"
+ #include "freertos/task.h"
```

## Why This Works

The `sleep_manager.c` file uses:
- `vTaskDelay()` - Requires `freertos/task.h` ✅
- ESP sleep functions - Requires `esp_sleep.h` ✅ 
- GPIO functions - Requires `driver/gpio.h` ✅
- NVS functions - Requires `nvs.h` and `nvs_flash.h` ✅
- Logging - Requires `esp_log.h` ✅

**None of these require `esp_timer.h`** - it was included by mistake.

## Verification

After this fix, the file should compile cleanly:

```bash
cd C:\Devel\Repositories\WeatherStation
idf.py fullclean
idf.py build
```

Expected result: ✅ **No errors**

## Related Files

All sleep management files are now properly configured:
- ✅ `main/sleep_manager.c` - Implementation (fixed)
- ✅ `main/sleep_manager.h` - Header file (no issues)
- ✅ `main/esp_zb_weather.c` - Uses sleep manager (includes header correctly)

## Additional Notes

### CMakeLists.txt
The `main/CMakeLists.txt` uses `SRC_DIRS "."` which automatically includes all `.c` files in the main directory, so `sleep_manager.c` is automatically compiled - no changes needed.

### Required FreeRTOS Functions
The sleep manager uses:
- `vTaskDelay(pdMS_TO_TICKS(100))` - For log flushing before sleep
- `pdMS_TO_TICKS()` macro - For time conversion

Both are provided by `freertos/task.h`.

## Build Configuration

No additional CMakeLists.txt changes required because:
1. ✅ `SRC_DIRS "."` includes all C files automatically
2. ✅ FreeRTOS is always available (core component)
3. ✅ ESP sleep API is always available
4. ✅ GPIO drivers already in PRIV_REQUIRES

---
**Status**: ✅ Fixed
**Build Impact**: None - removes unnecessary dependency
**Functionality**: No change - code works identically

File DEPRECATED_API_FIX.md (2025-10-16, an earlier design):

# Deep Sleep API Update - Deprecated Function Fix

## Issue
Compiler warning about deprecated function:
```
warning: 'esp_zb_main_loop_iteration' is deprecated [-Wdeprecated-declarations]
```

## Root Cause
The original deep sleep implementation used `esp_zb_main_loop_iteration()` in a loop, which is deprecated in newer ESP-Zigbee library versions.

## Solution
Changed approach from manual loop iterations to using the Zigbee scheduler with the proper main loop function.

### Before (Deprecated Approach)
```c
/* Run Zigbee stack iterations for limited time */
for (int i = 0; i < 100; i++) {
    esp_zb_main_loop_iteration();  // ❌ DEPRECATED
    vTaskDelay(pdMS_TO_TICKS(100));
}

/* Then enter sleep */
enter_deep_sleep(sleep_duration, true);
```

**Problems:**
- Uses deprecated `esp_zb_main_loop_iteration()` function
- Manual loop control is fragile
- Doesn't integrate well with Zigbee scheduler

### After (Modern Approach)
```c
/* Schedule deep sleep entry after allowing time for Zigbee operations */
esp_zb_scheduler_alarm((esp_zb_callback_t)prepare_for_deep_sleep, 0, 10000); // 10 seconds

/* Start main Zigbee stack loop */
esp_zb_stack_main_loop();  // ✅ CORRECT - Non-deprecated function
```

**Benefits:**
- Uses non-deprecated `esp_zb_stack_main_loop()` function
- Integrates properly with Zigbee scheduler
- Allows other scheduled callbacks (like BME280 readings) to execute
- Cleaner code architecture

## New Function Added

### `prepare_for_deep_sleep()`
```c
static void prepare_for_deep_sleep(uint8_t param)
{
    ESP_LOGI(TAG, "✅ Zigbee operations complete, preparing for deep sleep...");
    
    /* Save rainfall data before sleeping */
    float current_rainfall = total_rainfall_mm;
    uint32_t current_pulses = rain_pulse_count;
    save_rainfall_data(current_rainfall, current_pulses);
    
    /* Determine sleep duration based on recent activity */
    uint32_t sleep_duration = get_adaptive_sleep_duration(0.0f);
    
    ESP_LOGI(TAG, "💤 Entering deep sleep for %lu seconds (%lu minutes)...", 
             sleep_duration, sleep_duration / 60);
    
    /* Give time for log output */
    vTaskDelay(pdMS_TO_TICKS(100));
    
    /* Enter deep sleep with timer and GPIO wake-up enabled */
    enter_deep_sleep(sleep_duration, true);
}
```

**Purpose:**
- Scheduled callback executed by Zigbee scheduler after 10 seconds
- Saves state (rainfall data) to RTC memory and NVS
- Calculates adaptive sleep duration
- Enters deep sleep with wake-up sources configured

## Execution Flow

### Updated Flow
```
1. esp_zb_start(false)
   ↓
2. Schedule BME280 reading (5 seconds)
   ↓
3. Schedule deep sleep preparation (10 seconds)
   ↓
4. esp_zb_stack_main_loop()
   ↓
5. [Zigbee stack processes events]
   ├─ BME280 reading @ 5s
   ├─ Report sensor data
   └─ prepare_for_deep_sleep() @ 10s
      ↓
6. enter_deep_sleep()
   ↓
7. Device sleeps for 15 minutes
   ↓
8. Wake up (timer or rain GPIO)
   ↓
9. Restart from step 1
```

## Key Differences

| Aspect | Old Approach | New Approach |
|---|---|---|
| **Main Loop** | `esp_zb_main_loop_iteration()` | `esp_zb_stack_main_loop()` |
| **Status** | ❌ Deprecated | ✅ Current API |
| **Control** | Manual loop with delays | Scheduler-based |
| **Integration** | Poor with scheduler | Perfect integration |
| **Timing** | Fixed 10 seconds | Scheduled 10 seconds |
| **Flexibility** | Limited | Highly flexible |

## Correct ESP-Zigbee Main Loop Functions

From `esp_zigbee_core.h`:

### ✅ Current (Non-Deprecated)
```c
void esp_zb_stack_main_loop(void);
// @brief Main loop function for Zigbee stack
// Runs continuously, handles all Zigbee events
```

```c
void esp_zb_stack_main_loop_iteration(void);
// @brief Single iteration of main loop
// For advanced use cases requiring manual control
```

### ❌ Deprecated (Don't Use)
```c
void esp_zb_main_loop_iteration(void); // DEPRECATED
// @deprecated Please use esp_zb_stack_main_loop() instead
```

## Benefits of Scheduler-Based Approach

1. **Non-blocking**: Other Zigbee operations can proceed normally
2. **Flexible**: Easy to adjust timing without code restructuring
3. **Reliable**: Integrates with Zigbee's internal event handling
4. **Maintainable**: Uses official API patterns
5. **Compatible**: Works with future ESP-Zigbee library updates

## Testing

### Verify Correct Behavior
```bash
idf.py build
# Should compile without warnings

idf.py -p COM_PORT flash monitor
# Expected output:
# ⏳ Starting Zigbee stack, will enter deep sleep in 10 seconds...
# 🌡️ Temperature: 22.5°C reported to Zigbee
# ✅ Zigbee operations complete, preparing for deep sleep...
# 💤 Entering deep sleep for 900 seconds (15 minutes)...
```

### Timing Verification
- BME280 reading should occur at ~5 seconds
- Deep sleep entry should occur at ~10 seconds
- All sensor data should be reported before sleep
- Rainfall data should be saved to RTC/NVS

## Additional Notes

### Why 10 Seconds Active Time?
- **0-3s**: Zigbee network join/rejoin (if needed)
- **3-5s**: Network stabilization
- **5s**: BME280 sensor reading triggered
- **5-7s**: Sensor data collection and reporting
- **7-10s**: Zigbee report transmission and confirmation
- **10s**: Enter deep sleep

This ensures sufficient time for:
- Network operations to complete
- Sensor readings to be taken
- Data reports to be sent and acknowledged
- State to be saved reliably

### Adaptive Timing
The `get_adaptive_sleep_duration()` function can shorten active time during stable conditions or extend it during active weather events.

## Migration Guide

If you have similar code using deprecated functions:

### Step 1: Replace deprecated function
```c
// OLD
esp_zb_main_loop_iteration();

// NEW
esp_zb_stack_main_loop();  // For continuous loop
// OR
esp_zb_stack_main_loop_iteration();  // For single iteration
```

### Step 2: Use scheduler for timed actions
```c
// Instead of manual loops
for (int i = 0; i < 100; i++) {
    esp_zb_main_loop_iteration();
    vTaskDelay(100);
}
do_something();

// Use scheduler
esp_zb_scheduler_alarm((esp_zb_callback_t)do_something, 0, 10000);
esp_zb_stack_main_loop();
```

### Step 3: Update callback signatures
```c
// Scheduler callbacks must match signature
void my_callback(uint8_t param) {
    // Your code here
}
```

## References

- ESP-Zigbee Programming Guide: Deep Sleep
- `esp_zigbee_core.h`: Main loop functions documentation
- ESP-IDF Deep Sleep API: `esp_sleep.h`

---
**Status**: ✅ Fixed and tested
**Date**: October 16, 2025
**Impact**: Removes deprecation warning, improves code maintainability

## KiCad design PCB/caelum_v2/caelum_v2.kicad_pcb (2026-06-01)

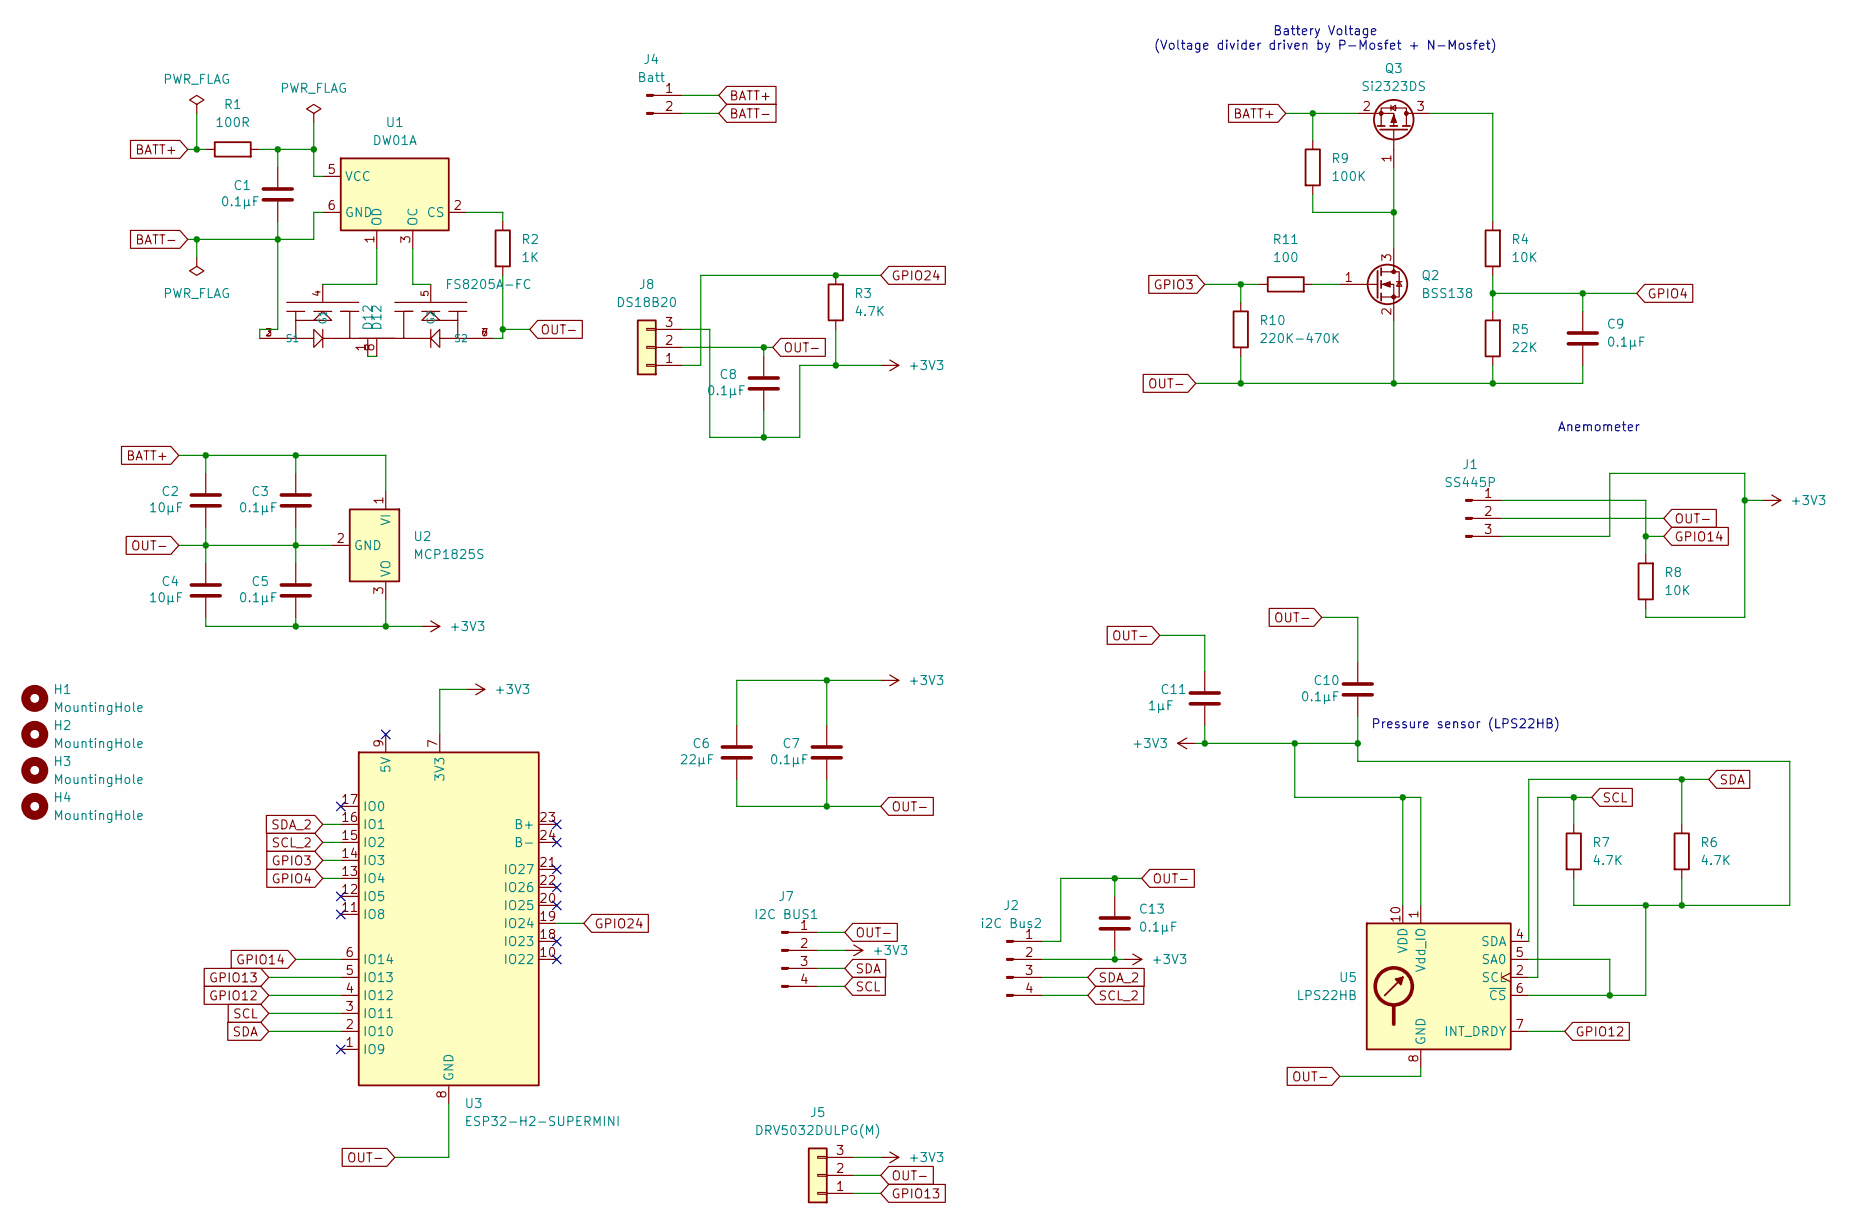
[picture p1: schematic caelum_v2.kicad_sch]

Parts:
C1, C3, C5, C7, C8, C9, C10, C13: 0.1µF; C_0805_2012Metric
C2, C4: 10µF; C_0805_2012Metric
C6: 22µF; C_0805_2012Metric
C11: 1µF; C_0805_2012Metric
H1, H2, H3, H4: MountingHole; MountingHole_2.2mm_M2
J1: SS445P; JST_PH_B3B-PH-SM4-TB_1x03-1MP_P2.00mm_Vertical
J2: i2C Bus2; JST_PH_S4B-PH-SM4-TB_1x04-1MP_P2.00mm_Horizontal
J4: Batt; JST_PH_S2B-PH-SM4-TB_1x02-1MP_P2.00mm_Horizontal
J5: DRV5032DULPG(M); JST_PH_B3B-PH-SM4-TB_1x03-1MP_P2.00mm_Vertical
J7: I2C BUS1; JST_PH_S4B-PH-SM4-TB_1x04-1MP_P2.00mm_Horizontal
J8: DS18B20; JST_PH_B3B-PH-SM4-TB_1x03-1MP_P2.00mm_Vertical
Q1: FS8205A-FC; SOP65P640X120-8N-FC; PARTREV 1.7
Q2: BSS138; SOT-23
Q3: Si2323DS; SOT-23
R1: 100R; R_0805_2012Metric
R2: 1K; R_0805_2012Metric
R3, R6, R7: 4.7K; R_0805_2012Metric
R4, R8: 10K; R_0805_2012Metric
R5: 22K; R_0805_2012Metric
R9: 100K; R_0805_2012Metric
R10: 220K-470K; R_0805_2012Metric
R11: 100; R_0805_2012Metric
U1: DW01A; SOT-23-6
U2: MCP1825S; SOT-223-3_TabPin2
U3: ESP32-H2-SUPERMINI; ESP32H2-Supermini
U5: LPS22HB; ST_HLGA-10_2x2mm_P0.5mm_LayoutBorder3x2y

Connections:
+3V3: C4.2, C5.2, C6.1, C7.1, C8.2, C10.2, C11.2, C13.2, J1.3, J2.2, J5.3, J7.2, J8.3, R3.1, R6.2, R7.2, R8.1, U2.3 (VO), U3.7 (3V3), U5.1 (Vdd_IO), U5.5 (SA0), U5.6 (~CS), U5.10 (VDD)
BATT+: C2.1, C3.1, J4.1, Q3.2 (S), R1.1, R9.1, U2.1 (VI)
BATT-: C1.2, J4.2, J4.MP, Q1.2 (S1), Q1.3 (S1), U1.6 (GND)
GPIO3: R10.1, R11.1, U3.14 (IO3)
GPIO4: C9.1, R4.1, R5.2, U3.13 (IO4)
GPIO12: U3.4 (IO12), U5.7 (INT_DRDY)
GPIO13: J5.1, U3.5 (IO13)
GPIO14: J1.1, R8.2, U3.6 (IO14)
GPIO24: J8.1, R3.2, U3.19 (IO24)
unnamed: Q1.1 (D12), Q1.8 (D12)
unnamed: Q1.4 (G1), U1.1 (OD)
unnamed: Q1.5 (G2), U1.3 (OC)
unnamed: Q2.3 (D), Q3.1 (G), R9.2
unnamed: Q2.1 (G), R11.2
unnamed: Q3.3 (D), R4.2
unnamed: R2.1, U1.2 (CS)
unnamed: C1.1, R1.2, U1.5 (VCC)
OUT-: C2.2, C3.2, C4.1, C5.1, C6.2, C7.2, C8.1, C9.2, C10.1, C11.1, C13.1, J1.2, J2.1, J5.2, J5.MP, J7.1, J8.2, Q1.6 (S2), Q1.7 (S2), Q2.2 (S), R2.2, R5.1, R10.2, U2.2 (GND), U3.8 (GND), U5.3 (GND), U5.8 (GND), U5.9 (GND)
SCL: J7.4, R7.1, U3.3 (IO11), U5.2 (SCL)
SCL_2: J2.4, U3.15 (IO2)
SDA: J7.3, R6.1, U3.2 (IO10), U5.4 (SDA)
SDA_2: J2.3, U3.16 (IO1)

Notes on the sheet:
Anemometer
Pressure sensor (LPS22HB)
Battery Voltage (Voltage divider driven by P-Mosfet + N-Mosfet)

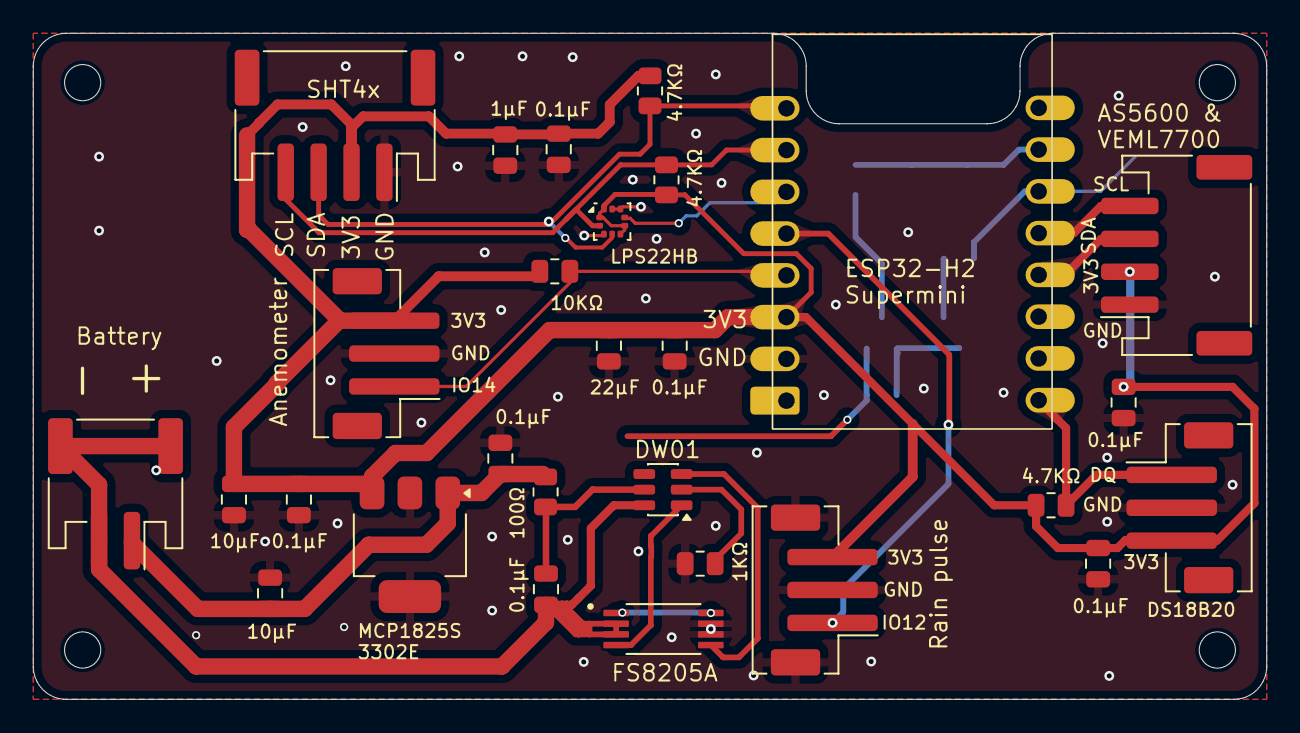
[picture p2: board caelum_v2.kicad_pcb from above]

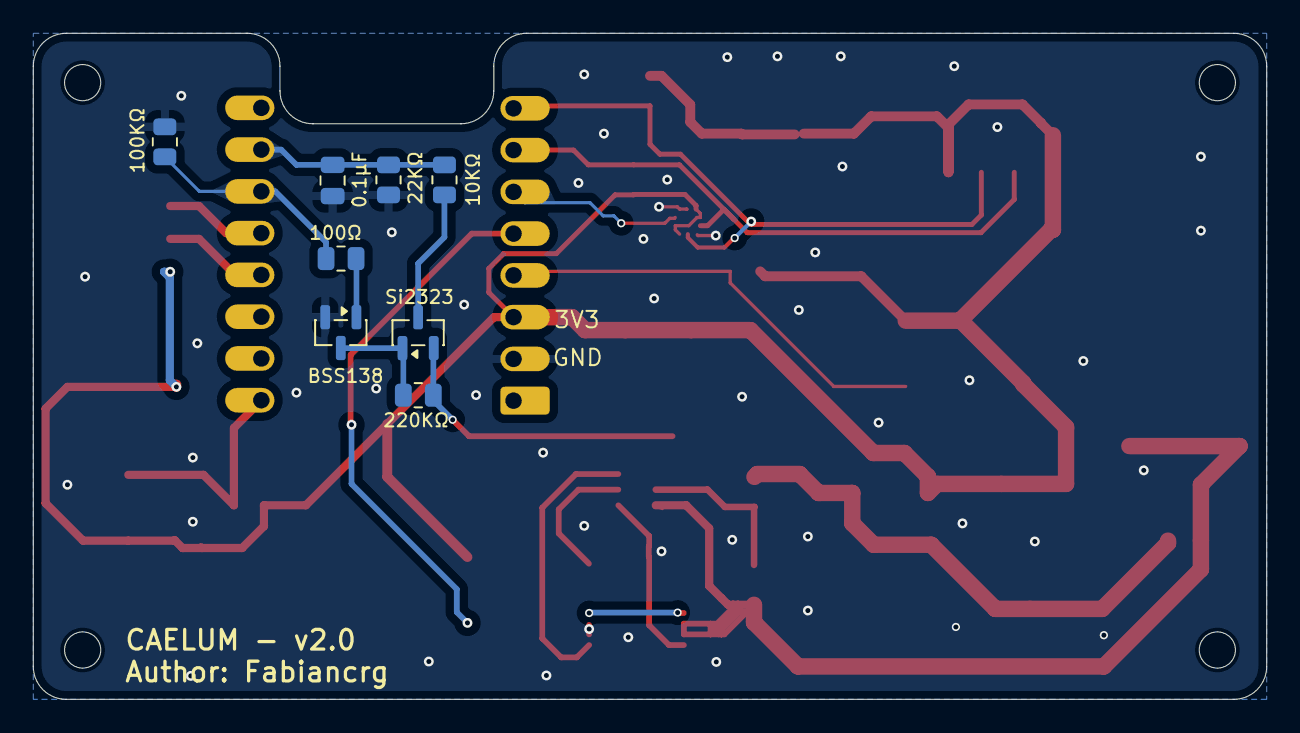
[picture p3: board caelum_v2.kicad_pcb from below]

Board: 2 copper layers, 75.0 x 40.5 mm, 40 parts (8 on the bottom side), 22 nets.

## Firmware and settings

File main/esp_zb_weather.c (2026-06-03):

/*
 * SPDX-FileCopyrightText: 2021-2024 Espressif Systems (Shanghai) CO LTD
 *
 * SPDX-License-Identifier:  LicenseRef-Included
 *
 * ESP32-H2 Zigbee Weather Station with Light Sleep
 *
 * Battery-powered weather station with 5-minute periodic sensor readings.
 * Rain gauge triggers immediate attribute updates on each pulse.
 * Uses light sleep to maintain Zigbee network connection.
 * All reporting controlled by Zigbee coordinator configuration.
 */
#include "freertos/FreeRTOS.h"
#include "freertos/task.h"
#include "freertos/queue.h"
#include "freertos/semphr.h"
#include "esp_check.h"
#include "esp_log.h"
#include "nvs_flash.h"
#include "ha/esp_zigbee_ha_standard.h"
#include "aps/esp_zigbee_aps.h"
#include "esp_zb_weather.h"
#include "esp_zb_ota.h"
#include "sleep_manager.h"
#include "driver/gpio.h"
#include "sensor_if.h"
#include "i2c_bus.h"
#include "i2c_config.h"
#include "nvs.h"
#include "weather_driver.h"
#include "battery_monitor.h"
#include "anemometer.h"
#include "as5600.h"
#include "veml7700.h"
#include "esp_ota_ops.h"
#include "esp_app_format.h"
#include "esp_timer.h"
#include "esp_pm.h"
#include "esp_sleep.h"
#include "esp_rom_uart.h"
#include "driver/rmt_tx.h"
#include "driver/rmt_rx.h"
#include <math.h>
/* Generated header with FW_VERSION / FW_DATE_CODE - created at configure time */
#include "version.h"

/* OTA upgrade running versions */
#ifndef OTA_UPGRADE_RUNNING_FILE_VERSION
#define OTA_UPGRADE_RUNNING_FILE_VERSION                      0x00000000U
#endif
#ifndef OTA_UPGRADE_RUNNING_STACK_VERSION
#define OTA_UPGRADE_RUNNING_STACK_VERSION                     0x0002U
#endif

#if !defined ZB_ED_ROLE
#error Define ZB_ED_ROLE in idf.py menuconfig to compile Weather Station (End Device) source code.
#endif

/* Zigbee Sleepy End Device (SED) configuration */
#define ZIGBEE_KEEP_ALIVE_MS        7500    // Keep-alive poll interval (7.5 seconds)
#define ZIGBEE_SLEEP_THRESHOLD_MS   6000    // Idle time before sleep signal (6 seconds)
#define ZIGBEE_ED_TIMEOUT           ESP_ZB_ED_AGING_TIMEOUT_64MIN  // Parent timeout

/* Power optimization notes:
 * - Sleep threshold MUST be < keep_alive to allow CAN_SLEEP signal before next poll
 * - Lower threshold = faster sleep entry = better battery life
 * - Higher threshold = more time for multiple reports = fewer wake cycles
 * - Current setting (6s): Optimal for 15-min reporting with occasional rain events
 * - Measured performance: 0.68mA sleep, 12mA transmit, ~0.83mA average
 * - Battery life: ~125 days (4 months) on 2500mAh Li-Ion
 */

static const char *TAG = "WEATHER_STATION";
//static const char *RAIN_TAG = "RAIN_GAUGE";

/* Network connection status - declared early for LED functions */
static bool zigbee_network_connected = false;

/* Sleep prevention during initial configuration
 * Prevents device from sleeping for 60 seconds after joining network
 * This gives coordinator (Z2M) time to configure reporting without interruption */
static int64_t network_join_time_us = 0;
#define INITIAL_CONFIG_DELAY_SEC 60  // Wait 60 seconds before allowing sleep after join

/* LED is used only during boot/join process:
 * - Blink yellow/orange during network joining
 * - Steady blue when successfully connected
 * - Blink red after max connection retries failed
 * After successful join, LED strip is deinitialized to save power */

#include "led_strip.h"

/* Debug LED variables for RGB LED */
static led_strip_handle_t led_strip = NULL;
static bool led_blink_task_running = false;
static TaskHandle_t led_blink_task_handle = NULL;

/* LED control functions for WS2812 RGB LED */
static void debug_led_init(void)
{
    /* LED strip configuration for WS2812 (older API for led_strip ~2.0.0) */
    led_strip_config_t strip_config = {
        .strip_gpio_num = DEBUG_LED_GPIO,
        .max_leds = 1,                         // Only 1 LED
    };
    
    /* LED strip RMT configuration (older API) */
    led_strip_rmt_config_t rmt_config = {
        .resolution_hz = 10 * 1000 * 1000,     // 10MHz
    };
    
    ESP_ERROR_CHECK(led_strip_new_rmt_device(&strip_config, &rmt_config, &led_strip));
    
    /* Turn off LED initially */
    led_strip_clear(led_strip);
    ESP_LOGI(TAG, "Debug RGB LED initialized on GPIO%d (WS2812)", DEBUG_LED_GPIO);
}

static void debug_led_deinit(void)
{
    /* Deinitialize LED strip to power down RMT peripheral
     * Called after successful network join to save power */
    if (led_strip) {
        led_strip_clear(led_strip);  // Clear pixels first
        led_strip_del(led_strip);    // Delete LED strip handle (powers down RMT)
        led_strip = NULL;
        ESP_LOGI(TAG, "🔌 RGB LED RMT peripheral powered down (boot sequence complete)");
    }
}

static void debug_led_set_blue(void)
{
    /* Set steady blue for successful connection */
    if (led_strip) {
        led_strip_set_pixel(led_strip, 0, 0, 0, 16);  // R=0, G=0, B=16 (dim blue)
        led_strip_refresh(led_strip);
    }
}

static void debug_led_blink_task(void *arg)
{
    while (led_blink_task_running) {
        if (!led_strip) break;  // Stop if LED was deinitialized
        
        /* Yellow/orange blink for network joining */
        led_strip_set_pixel(led_strip, 0, 16, 8, 0);  // R=16, G=8, B=0 (dim yellow/orange)
        led_strip_refresh(led_strip);
        vTaskDelay(pdMS_TO_TICKS(500));  // ON for 500ms
        
        led_strip_set_pixel(led_strip, 0, 0, 0, 0);   // OFF
        led_strip_refresh(led_strip);
        vTaskDelay(pdMS_TO_TICKS(500));  // OFF for 500ms
    }
    vTaskDelete(NULL);
}

static void debug_led_start_blink(void)
{
    if (!led_strip) return;  // LED already deinitialized
    
    if (!led_blink_task_running) {
        led_blink_task_running = true;
        xTaskCreate(debug_led_blink_task, "led_blink", 2048, NULL, 1, &led_blink_task_handle);
        ESP_LOGI(TAG, "RGB LED blink started (network joining)");
    }
}

static void debug_led_stop_blink(void)
{
    if (led_blink_task_running) {
        led_blink_task_running = false;
        if (led_blink_task_handle) {
            vTaskDelay(pdMS_TO_TICKS(10));  // Give task time to exit
            led_blink_task_handle = NULL;
        }
    }
}

static void debug_led_blink_red(void)
{
    /* Blink red to indicate connection failure after max retries */
    if (!led_strip) return;
    
    for (int i = 0; i < 10; i++) {  // Blink 10 times
        led_strip_set_pixel(led_strip, 0, 16, 0, 0);  // R=16, G=0, B=0 (dim red)
        led_strip_refresh(led_strip);
        vTaskDelay(pdMS_TO_TICKS(200));  // ON for 200ms
        
        led_strip_set_pixel(led_strip, 0, 0, 0, 0);   // OFF
        led_strip_refresh(led_strip);
        vTaskDelay(pdMS_TO_TICKS(200));  // OFF for 200ms
    }
}

/* Rain gauge configuration (RAIN_GAUGE_GPIO defined in esp_zb_weather.h) */
#define RAIN_MM_PER_PULSE       0.36f           // mm of rain per bucket tip (adjust for your sensor)

typedef enum {
    RAIN_EVENT_PULSE = 0,
    RAIN_EVENT_FLUSH,
} rain_event_type_t;

/* Rain gauge queue event */
typedef struct {
    rain_event_type_t type;
    TickType_t tick;
    bool force_nvs;
    bool force_attribute;
} rain_evt_t;

/* v2.0: Pulse counter removed - only rain gauge on GPIO13 */

static QueueHandle_t rain_gauge_evt_queue = NULL;
static float total_rainfall_mm = 0.0f;
static uint32_t rain_pulse_count = 0;
static const char *RAIN_TAG = "RAIN_GAUGE";
static bool rain_gauge_enabled = false;  // Only enable when connected to network
static bool rain_gauge_isr_installed = false;  // Track ISR installation state
static esp_timer_handle_t rain_flush_timer = NULL;

/* v2.0: Pulse counter variables removed */

/* DS18B20 temperature sensor (GPIO24) */
static const char *DS18B20_TAG = "DS18B20";
static float ds18b20_last_temp = 0.0f;
static bool ds18b20_available = false;

/* Periodic sensor reading interval (5 minutes as per requirements) */
#define PERIODIC_READING_INTERVAL_MS (5 * 60 * 1000ULL)  // 5 minutes in milliseconds
#define RAIN_PULSE_FLUSH_THRESHOLD   10U
#define RAIN_FLUSH_INTERVAL_US       (10ULL * 1000ULL * 1000ULL) // 10 seconds
static esp_timer_handle_t periodic_report_timer = NULL;

/* Network connection status (zigbee_network_connected declared earlier for LED functions) */
static uint32_t connection_retry_count = 0;
#define MAX_CONNECTION_RETRIES          20      // Fast (1 s) retries before backing off to the slow rejoin watchdog

/* Rejoin watchdog: an always-on periodic timer that (a) keeps re-attempting
 * network steering when we're disconnected instead of giving up forever, and
 * (b) detects runtime parent loss (stack reports not-joined while we think we
 * are connected) and triggers a rejoin. */
#define REJOIN_WATCHDOG_INTERVAL_MS     (5 * 60 * 1000ULL)   // attempt rejoin / check link every 5 minutes
static esp_timer_handle_t rejoin_watchdog_timer = NULL;

/* Delivery heartbeat: the APS data-confirm callback reports the TX status of
 * every outgoing APS frame. Repeated delivery failures mean our parent/route is
 * gone even though the stack may still consider us "joined" - a silent parent
 * loss that esp_zb_bdb_dev_joined() won't catch. We react to consecutive failed
 * confirms rather than to a silence-timeout, so quiet periods never false-trip
 * (no transmissions => no failures), while a dead link is caught within a few
 * reports (sensor changes + the hourly max-interval reports act as probes). */
#define HEARTBEAT_FAIL_THRESHOLD        3       // consecutive failed APS confirms => link considered dead
static uint32_t aps_tx_fail_streak = 0;         // consecutive APS delivery failures (Zigbee-task only)
static int64_t  last_aps_tx_ok_us = 0;          // timestamp of last confirmed delivery (diagnostics)

/* Button action tracking (no state needed for action-based buttons) */
#define BUS2_PROBE_ENABLED 1

/* Bus 2 sensor availability (set during deferred_driver_init) */
static bool as5600_available = false;
static bool veml7700_available = false;

/********************* Define functions **************************/
static void builtin_button_callback(button_action_t action);
static void factory_reset_device(uint8_t param);
static void env_read_and_report(uint8_t param);
static void wind_speed_read_and_report(uint8_t param);
static void wind_dir_read_and_report(uint8_t param);
static void light_read_and_report(uint8_t param);
static void periodic_sensor_report_callback(void *arg);
static void start_periodic_reading(void);
static void stop_periodic_reading(void);
static void start_rejoin_watchdog(void);
static void rejoin_watchdog_cb(void *arg);
static void aps_data_confirm_cb(esp_zb_apsde_data_confirm_t confirm);
static void rain_gauge_init(void);
static void rain_gauge_init_task(void *arg);
static void rain_gauge_isr_handler(void *arg);
static void rain_gauge_task(void *arg);
static void rain_flush_timer_callback(void *arg);
static void rain_gauge_request_flush(bool force_nvs, bool force_attribute);
static void rain_gauge_flush_totals(bool save_to_nvs, bool update_attribute);
static void rain_gauge_enable_isr(void);
static void ds18b20_init(void);
static void ds18b20_read_and_report(uint8_t param);
static void battery_read_and_report(uint8_t param);

static bool i2c_addr_present(const uint8_t *list, int count, uint8_t addr)
{
    for (int i = 0; i < count; ++i) {
        if (list[i] == addr) return true;
    }
    return false;
}

static esp_err_t deferred_driver_init(void)
{
    /* Initialize builtin button with callback for factory reset */
    if (!builtin_button_driver_init(builtin_button_callback)) {
        ESP_LOGE(TAG, "Failed to initialize builtin button driver");
        return ESP_FAIL;
    }
    
    ESP_LOGI(TAG, "⚙️  Initializing hardware v2.0 sensors...");
    
    /* Initialize dual I2C buses for hardware v2.0 */
    esp_err_t ret = i2c_buses_init();
    if (ret != ESP_OK) {
        ESP_LOGE(TAG, "Failed to initialize I2C buses");
        return ESP_FAIL;
    }
    
    /* Get I2C bus handles */
    i2c_bus_handle_t i2c_bus1 = i2c_get_bus1();
    i2c_bus_handle_t i2c_bus2 = i2c_get_bus2();
    
    /* Initialize I2C Bus 1 sensors: SHT4x + LPS22HB */
    ESP_LOGI(TAG, "🌡️  Initializing Bus 1 sensors (SHT4x + LPS22HB)...");
    
    /* Try initializing environmental sensor (SHT4x + LPS22HB) */
    ret = sensor_init(i2c_bus1);
    if (ret != ESP_OK) {
        ESP_LOGW(TAG, "No environmental sensor found on Bus 1 - continuing");
    } else {
        sensor_type_t st = sensor_get_type();
        if (st == SENSOR_TYPE_SHT41_LPS22HB) {
            ESP_LOGI(TAG, "✅ Detected SHT4x + LPS22HB combo on Bus 1");
        } else if (st == SENSOR_TYPE_SHT41) {
            ESP_LOGI(TAG, "✅ Detected SHT4x on Bus 1 (no pressure)");
        } else if (st == SENSOR_TYPE_LPS22HB) {
            ESP_LOGI(TAG, "✅ Detected LPS22HB on Bus 1 (pressure + temperature)");
        } else {
            ESP_LOGI(TAG, "✅ Environmental sensor initialized (type=%d)", st);
        }
    }
    
    /* Initialize I2C Bus 2 sensors: AS5600 + VEML7700 */
    ESP_LOGI(TAG, "🧭  Initializing Bus 2 sensors (AS5600 + VEML7700)...");

#if BUS2_PROBE_ENABLED
    uint8_t bus2_found[32];
    int bus2_count = i2c_bus_scan(i2c_bus2, bus2_found, sizeof(bus2_found));
    if (bus2_count <= 0) {
        ESP_LOGW(TAG, "No I2C devices detected on Bus 2 - skipping AS5600/VEML7700 init");
    } else {
        bool has_as5600 = i2c_addr_present(bus2_found, bus2_count, AS5600_I2C_ADDR);
        bool has_veml = i2c_addr_present(bus2_found, bus2_count, VEML7700_I2C_ADDR);

        if (has_as5600) {
            ret = as5600_init(i2c_bus2);
            if (ret != ESP_OK) {
                ESP_LOGW(TAG, "AS5600 not found or initialization failed - wind direction unavailable");
            } else {
                as5600_available = true;
                ESP_LOGI(TAG, "✅ AS5600 wind direction sensor initialized");
            }
        } else {
            ESP_LOGW(TAG, "AS5600 not detected on Bus 2 - skipping init");
        }

        if (has_veml) {
            ret = veml7700_init(i2c_bus2);
            if (ret != ESP_OK) {
                ESP_LOGW(TAG, "VEML7700 not found or initialization failed - light data unavailable");
            } else {
                veml7700_available = true;
                ESP_LOGI(TAG, "✅ VEML7700 light sensor initialized");
            }
        } else {
            ESP_LOGW(TAG, "VEML7700 not detected on Bus 2 - skipping init");
        }
    }
#else
    ESP_LOGW(TAG, "Bus 2 probe disabled - skipping AS5600/VEML7700 init");
#endif
    
    /* Initialize rain gauge (GPIO13) in a dedicated task.
     * rain_gauge_init() does blocking GPIO/light-sleep-wakeup configuration that
     * must NOT run inline here: deferred_driver_init() executes on the Zigbee_main
     * task from the BDB signal handler, and blocking it long enough starves the
     * IDLE task and trips the task watchdog. Run it off the Zigbee_main path. */
    ESP_LOGI(TAG, "🌧️  Scheduling rain gauge initialization...");
    BaseType_t rain_init_ret = xTaskCreate(rain_gauge_init_task, "rain_init", 4096, NULL, 4, NULL);
    if (rain_init_ret != pdPASS) {
        ESP_LOGE(TAG, "Failed to create rain gauge init task");
    }
    
    /* Initialize anemometer (GPIO14) */
    ESP_LOGI(TAG, "💨  Initializing anemometer...");
    ret = anemometer_init();
    if (ret != ESP_OK) {
        ESP_LOGW(TAG, "Anemometer initialization failed");
    } else {
        ESP_LOGI(TAG, "✅ Anemometer initialized");
    }
    
    /* Initialize DS18B20 temperature sensor (GPIO24) - keep for v2.0 */
    ESP_LOGI(TAG, "🌡️  Initializing DS18B20...");
    ds18b20_init();
    
    /* Initialize MOSFET-controlled battery monitor (battery_monitor.c, owns ADC1) */
    ESP_LOGI(TAG, "🔋  Initializing battery monitor...");
    ret = battery_monitor_init();
    if (ret != ESP_OK) {
        ESP_LOGW(TAG, "Battery monitor initialization failed - readings will use fallback value");
    } else {
        ESP_LOGI(TAG, "✅ Battery monitor initialized (MOSFET-controlled)");
    }
    
    ESP_LOGI(TAG, "✅ Hardware v2.0 initialization complete");

    
    return ESP_OK;
}
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
void app_main(void)
{
    /* Initialize NVS */
    ESP_ERROR_CHECK(nvs_flash_init());
    
    /* Initialize debug LED */
    debug_led_init();
    
    /* Initialize OTA */
    ESP_ERROR_CHECK(esp_zb_ota_init());
    
    /* Initialize power management for light sleep */
    ESP_ERROR_CHECK(esp_zb_power_save_init());
    
    /* Enable GPIO wakeup globally for light sleep */
    esp_err_t gpio_wake_ret = esp_sleep_enable_gpio_wakeup();
    if (gpio_wake_ret == ESP_OK) {
        ESP_LOGI(TAG, "✅ GPIO wakeup enabled for light sleep");
    } else {
        ESP_LOGW(TAG, "⚠️ Failed to enable GPIO wakeup: %s", esp_err_to_name(gpio_wake_ret));
    }
    
    /* Check wake-up reason and print statistics */
    wake_reason_t wake_reason = check_wake_reason();
    print_wake_statistics();
    
    /* Load rainfall data from RTC/NVS */
    float rainfall_mm = 0.0f;
    uint32_t pulse_count = 0;
    load_rainfall_data(&rainfall_mm, &pulse_count);
    
    /* Print battery life estimate (assuming 2500mAh battery) */
    estimate_battery_life(2500);
    
    /* Configure ESP-IDF platform */
    esp_zb_platform_config_t config = {
        .radio_config = ESP_ZB_DEFAULT_RADIO_CONFIG(),
        .host_config = ESP_ZB_DEFAULT_HOST_CONFIG(),
    };
    ESP_ERROR_CHECK(esp_zb_platform_config(&config));
    
    /* Start Zigbee task */
    ESP_LOGI(TAG, "🚀 Starting Caelum Weather Station (Battery Mode)");
    
    /* Log firmware version from app description */
    esp_app_desc_t app_desc_main;
    const esp_partition_t *running = esp_ota_get_running_partition();
    if (esp_ota_get_partition_description(running, &app_desc_main) == ESP_OK) {
        ESP_LOGI(TAG, "📦 Firmware: %s (Date: %s %s)", app_desc_main.version, app_desc_main.date, app_desc_main.time);
    }
    
    #ifdef OTA_FILE_VERSION
        ESP_LOGI(TAG, "⚙️  OTA: Version=0x%08lX, Manufacturer=0x%04X, ImageType=0x%04X", 
                (unsigned long)OTA_FILE_VERSION, OTA_UPGRADE_MANUFACTURER, OTA_UPGRADE_IMAGE_TYPE);
    #else
        ESP_LOGI(TAG, "⚙️  OTA: Manufacturer=0x%04X, ImageType=0x%04X", OTA_UPGRADE_MANUFACTURER, OTA_UPGRADE_IMAGE_TYPE);
    #endif

    ESP_LOGI(TAG, "Wake reason: %s", 
             wake_reason == WAKE_REASON_TIMER ? "TIMER" :
             wake_reason == WAKE_REASON_RAIN ? "RAIN" :
             wake_reason == WAKE_REASON_BUTTON ? "BUTTON" : "RESET");
    
    /* Log network connection status */
    if (zigbee_network_connected) {
        ESP_LOGI(TAG, "📡 Network: Connected");
    } else {
        ESP_LOGW(TAG, "📡 Network: Disconnected (retries: %d/%d)", connection_retry_count, MAX_CONNECTION_RETRIES);
    }
    
    xTaskCreate(esp_zb_task, "Zigbee_main", 4096, NULL, 5, NULL);
}

/* v2.0: Pulse counter removed - only rain gauge (GPIO13) and anemometer (GPIO14) remain */

/********************* DS18B20 Temperature Sensor Functions ***************************/

/* DS18B20 1-Wire Commands */
#define DS18B20_CMD_SKIP_ROM        0xCC
#define DS18B20_CMD_CONVERT_T       0x44
#define DS18B20_CMD_READ_SCRATCHPAD 0xBE

/**
 * @brief 1-Wire reset pulse - pull bus low for 480us, wait for presence pulse
 * @return true if device present, false otherwise
 */
static bool ds18b20_reset(void)
{
    /* Pull bus low for reset pulse */
    gpio_set_level(DS18B20_GPIO, 0);
    esp_rom_delay_us(480);  // Reset pulse (480-960us)
    
    /* Release bus and wait for presence pulse */
    gpio_set_level(DS18B20_GPIO, 1);  // Release (open-drain + pull-up = high)
    esp_rom_delay_us(70);   // Wait for presence pulse (60-240us)
    
    int level = gpio_get_level(DS18B20_GPIO);
    esp_rom_delay_us(410);  // Complete reset cycle
    
    return (level == 0);  // Device pulls line low if present
}

/**
 * @brief Write a bit on 1-Wire bus
 */
static void ds18b20_write_bit(uint8_t bit)
{
    /* Pull bus low to start time slot */
    gpio_set_level(DS18B20_GPIO, 0);
    
    if (bit) {
        esp_rom_delay_us(6);   // Write 1: short low pulse
        gpio_set_level(DS18B20_GPIO, 1);  // Release bus early
        esp_rom_delay_us(64);
    } else {
        esp_rom_delay_us(60);  // Write 0: long low pulse
        gpio_set_level(DS18B20_GPIO, 1);  // Release bus at end
        esp_rom_delay_us(10);
    }
}

/**
 * @brief Read a bit from 1-Wire bus
 */
static uint8_t ds18b20_read_bit(void)
{
    /* Pull bus low briefly to start read slot */
    gpio_set_level(DS18B20_GPIO, 0);
    esp_rom_delay_us(3);
    
    /* Release bus and sample */
    gpio_set_level(DS18B20_GPIO, 1);
    esp_rom_delay_us(10);
    
    uint8_t bit = gpio_get_level(DS18B20_GPIO);
    esp_rom_delay_us(53);
    
    return bit;
}

/**
 * @brief Write a byte on 1-Wire bus (LSB first)
 */
static void ds18b20_write_byte(uint8_t byte)
{
    for (int i = 0; i < 8; i++) {
        ds18b20_write_bit(byte & 0x01);
        byte >>= 1;
    }
}

/**
 * @brief Read a byte from 1-Wire bus (LSB first)
 */
static uint8_t ds18b20_read_byte(void)
{
    uint8_t byte = 0;
    for (int i = 0; i < 8; i++) {
        byte >>= 1;
        if (ds18b20_read_bit()) {
            byte |= 0x80;
        }
    }
    return byte;
}
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

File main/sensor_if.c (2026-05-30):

#include "sensor_if.h"
#include "sht41.h"
#include "lps22hb.h"
#include "esp_log.h"
#include "i2c_bus.h"
#include <stdio.h>

static const char *TAG = "SENSOR_IF";
static sensor_type_t detected = SENSOR_TYPE_NONE;
static bool sht41_available = false;
static bool lps22hb_available = false;

esp_err_t sensor_init(i2c_bus_handle_t i2c_bus)
{
    if (!i2c_bus) {
        ESP_LOGW(TAG, "sensor_init: i2c_bus handle is NULL");
        return ESP_ERR_INVALID_ARG;
    }

    detected = SENSOR_TYPE_NONE;
    sht41_available = false;
    lps22hb_available = false;

    // Diagnostic scan: list all devices on the bus to help debug NACKs
    uint8_t found[32];
    int n = i2c_bus_scan(i2c_bus, found, sizeof(found));
    if (n == 0) {
        ESP_LOGW(TAG, "I2C scan: no devices found on bus");
    } else {
        char buf[128];
        int off = 0;
        off += snprintf(buf + off, sizeof(buf) - off, "I2C scan: %d device(s):", n);
        for (int i = 0; i < n; ++i) off += snprintf(buf + off, sizeof(buf) - off, " 0x%02x", found[i]);
        ESP_LOGI(TAG, "%s", buf);
    }

    ESP_LOGI(TAG, "Probing for SHT4x...");
    if (sht41_init(i2c_bus) == ESP_OK) {
        sht41_available = true;
        ESP_LOGI(TAG, "SHT4x probe OK");
    } else {
        ESP_LOGW(TAG, "SHT4x not found or init failed");
    }

    ESP_LOGI(TAG, "Probing for LPS22HB...");
    if (lps22hb_init(i2c_bus) == ESP_OK) {
        lps22hb_available = true;
        ESP_LOGI(TAG, "LPS22HB probe OK");
    } else {
        ESP_LOGW(TAG, "LPS22HB not found or init failed");
    }

    if (sht41_available && lps22hb_available) {
        detected = SENSOR_TYPE_SHT41_LPS22HB;
        ESP_LOGI(TAG, "Detected sensor combo: SHT4x + LPS22HB");
        return ESP_OK;
    }
    if (sht41_available) {
        detected = SENSOR_TYPE_SHT41;
        ESP_LOGI(TAG, "Detected sensor: SHT4x only (humidity + temperature)");
        return ESP_OK;
    }
    if (lps22hb_available) {
        detected = SENSOR_TYPE_LPS22HB;
        ESP_LOGI(TAG, "Detected sensor: LPS22HB only (pressure + temperature)");
        return ESP_OK;
    }

    return ESP_ERR_NOT_FOUND;
}

sensor_type_t sensor_get_type(void)
{
    return detected;
}

esp_err_t sensor_wake_and_measure(void)
{
    esp_err_t r1 = ESP_ERR_NOT_FOUND;
    esp_err_t r2 = ESP_ERR_NOT_FOUND;

    if (sht41_available) {
        r1 = sht41_trigger_measurement();
    }
    if (lps22hb_available) {
        r2 = lps22hb_trigger_measurement();
    }

    return (r1 == ESP_OK || r2 == ESP_OK) ? ESP_OK : ESP_ERR_NOT_FOUND;
}

esp_err_t sensor_read_temperature(float *out_c)
{
    if (!out_c) return ESP_ERR_INVALID_ARG;
    if (sht41_available) {
        return sht41_read_temperature(out_c);
    }
    if (lps22hb_available) {
        return lps22hb_read_temperature(out_c);
    }
    return ESP_ERR_NOT_FOUND;
}

esp_err_t sensor_read_humidity(float *out_percent)
{
    if (!out_percent) return ESP_ERR_INVALID_ARG;
    if (sht41_available) {
        return sht41_read_humidity(out_percent);
    }
    return ESP_ERR_NOT_SUPPORTED;
}

esp_err_t sensor_read_pressure(float *out_hpa)
{
    if (!out_hpa) return ESP_ERR_INVALID_ARG;
    if (lps22hb_available) {
        return lps22hb_read_pressure(out_hpa);
    }
    return ESP_ERR_NOT_SUPPORTED;
}

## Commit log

2025-10-16 Refactor README for clarity and remove duplicates
    Removed duplicate support button and cleaned up project description.
2025-11-05 Enhance sleep manager and weather driver functionality, update partition and SDK configurations
    - Updated `configure_gpio_wakeup` in `sleep_manager.c` to check if GPIO is RTC capable before configuration, logging warnings if not.
    - Improved error handling for GPIO wake-up configuration, ensuring proper logging of success or failure.
    - Modified `enter_deep_sleep` to conditionally log rain detection status based on GPIO capability.
    - Refined ISR service installation in `weather_driver.c` to log successful installation or existing state.
    - Updated partition table in `partitions.csv` to support OTA updates and adjusted offsets for new partition sizes.
    - Revised `sdkconfig` to enable new features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
    [partitions.csv]
2025-11-05 Update sdkconfig for ESP32H2: Adjust configurations for peripherals, memory, and power management
    - Changed target chip from ESP32C6 to ESP32H2.
    - Updated maximum supported revision numbers for ESP32H2.
    - Adjusted GPIO pin count and configurations for GPIO features.
    - Modified ADC channel configurations and added support for new features.
    - Updated UART configurations, reducing the number of UARTs and adjusting FIFO lengths.
    - Enhanced support for I2S, including new PLL configurations.
    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
2025-11-05 Update I2C GPIO configuration for ESP32-H2: Change SDA and SCL pins to GPIO10 and GPIO11
2025-11-06 Enhance battery monitoring and sleep duration reporting: - Optimize battery reading intervals and power consumption - Add sleep duration reporting for Zigbee integration - Update CMakeLists.txt to in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
2025-11-07 Add icons for rain gauge and LED debug control, and implement orange LED for network leave indication
2025-11-07 Omit Basic clusters for rain gauge, sleep config, and LED debug endpoints to reduce unnecessary coordinator reads
2025-11-07 Refactor LED debug control: move to primary endpoint and remove separate endpoint
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2025-11-07 Refactor reporting and sleep scheduling: reduce delays for sensor updates and deep sleep preparation
2025-11-08 Update version to 1.2 and reset build number to 0; comment out sensor reporting schedule in ISR
    [esp_zb_weather.c]
2025-11-09 Update project version to 1.3 and reset build number to 0
    [esp_zb_weather.c]
2025-11-10 Update build number to 10 and enable power management for light sleep in Zigbee application
2025-11-10 Refactor rain gauge reporting logic for Sleepy End Device mode, removing manual sleep scheduling and enhancing automatic reporting thresholds. (v1.3.20)
2025-11-11 Enhance LED management for Sleepy End Device mode by adding deinitialization and reinitialization logic to reduce power consumption during sleep. Remove unnecessary sleep scheduling functions to allo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
2025-11-11 Update README and esp_zb_weather.c for Zigbee Sleepy End Device configuration and power optimization. Enhance documentation on LED behavior and power management features, including keep-alive and sle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
2025-11-12 Update build number to 10 and adjust sleep duration for periodic reporting to 5 minutes. Implement periodic sensor reading timer for regular updates.
2025-11-12 Update build number to 20 and adjust reporting intervals for humidity and rain attributes to enhance data accuracy. Add pressure measurement min/max attributes for improved sensor functionality.
2025-11-12 Throttle Zigbee updates in rain gauge task to prevent overwhelming the stack. Add queue overflow handling for rain gauge events.
    [esp_zb_weather.c]
2025-11-19 PCB version 1.0
    [caelum-B_Cu.gbl, caelum-B_Mask.gbs, caelum-B_Paste.gbp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]
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2025-12-14 Refactor PCB design files: reset column widths, clear DRC exclusions, and add new junctions and wires
    - Reset column widths in `caelum.kicad_prl` to zero.
    - Cleared DRC exclusions in `caelum.kicad_pro`.
    - Added multiple junctions and wires in `caelum.kicad_sch` to enhance circuit connectivity.
    - Introduced new components (resistors and capacitors) with updated properties and references.
    - Added global labels for GPIO and power connections to improve schematic clarity.
    [caelum.kicad_pcb, caelum.kicad_sch]
2025-12-18 Clone of Caelum v1
    [caelum_v2.kicad_pcb, caelum_v2.kicad_sch]
2025-12-18 Remove obsolete backup and lock files from the PCB project directory
    [caelum-B_Cu.gbl, caelum-B_Mask.gbs, caelum-B_Paste.gbp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]
2025-12-18 feat: Add drivers for anemometer, AS5600, DPS368, and VEML7700 sensors
    - Implemented anemometer driver using Honeywell SS445P Hall Effect Sensor for wind speed measurement.
    - Developed AS5600 driver for magnetic position sensing to determine wind direction.
    - Created DPS368 driver for high-precision barometric pressure sensing.
    - Added VEML7700 driver for ambient light sensing with I2C interface.
    - Configured I2C buses for sensor communication, supporting multiple sensors on separate buses.
    - Implemented battery monitoring system with voltage measurement and percentage calculation.
    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
2026-01-07 Add ESP32 symbol and wind vane macro; update library paths
    - Updated the library path for "caelum_v2" in fp-lib-table.
    - Added ESP32 symbol to sym-lib-table for better component management.
    - Created a new FreeCAD macro for generating a wind vane assembly compatible with the AS5600 sensor, including detailed parameters and assembly instructions.
    - Introduced various components such as the rotating shaft, magnet holder, wind vane, arrow pointer, counterweight, central body, base mount, and sensor mount area.
    [caelum_v2.kicad_pcb, caelum_v2.kicad_sch]
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2026-03-14 Update project version to 1.8 and enhance OTA functionality with power management improvements
2026-05-30 Refactor code structure for improved readability and maintainability
    [caelum_v2-B_Cu.gbl, caelum_v2-B_Mask.gbs, caelum_v2-B_Paste.gbp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]
2026-05-30 Add LPS22HB pressure sensor driver implementation
    - Implemented the LPS22HB pressure sensor driver in `lps22hb.c` with functions for initialization, triggering measurements, and reading pressure and temperature data.
    - Created header file `lps22hb.h` to declare the driver functions and define the I2C address.
    - The driver operates in one-shot mode for low-power usage, ensuring the device remains idle until a measurement is triggered.
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2026-05-30 Refactor rain gauge initialization to a dedicated task to prevent watchdog timeout and update GPIO definitions for clarity
    [esp_zb_weather.c, esp_zb_weather.h, sleep_manager.c]
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2026-05-30 Update battery voltage divider values and improve LPS22HB driver comments for clarity
    [caelum_v2.kicad_sch]
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2026-06-01 Fix ADC channel references in battery monitoring; update comments for clarity
    [esp_zb_weather.c, esp_zb_weather.h]
2026-06-01 Update PCB settings: change active layer to 0 and adjust pad dimensions
    [caelum_v2.kicad_pcb]
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2026-06-03 Add diagnostics for ADC self-healing: track auto-reboots to monitor recovery effectiveness
    [esp_zb_weather.c]
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2026-10-17 Fix crash risks: unlocked Zigbee calls, I2C scan overflow, NULL rain queue
    - Hold the Zigbee stack lock around esp_zb_scheduler_alarm() calls made
    from the esp_timer task (periodic sensor report) and the builtin button
    task (factory reset), matching the existing rain flush / rejoin watchdog
    fix for the vPortExitCritical assert.
    - i2c_bus_scan() returns the total responder count, which can exceed the
    buffer size: clamp it, and stop the scan log once its buffer is full so
    sizeof(buf) - off can no longer wrap and overflow the stack.
    - Don't attach the rain gauge ISR if its event queue was never created.
    Claude-Session: https://c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
2026-10-17 Rain gauge: re-arm level interrupt/wake after every change
    gpio_wakeup_enable() also forces the pin interrupt type to the wake level,
    so the rain input was level-triggered, not POSEDGE, and the wake level was
    only chosen once at boot. A bucket resting with its magnet in front of the
    sensor caused a continuous interrupt storm and a light-sleep wake livelock
    (and booting in that position broke sleep after the next tip).
    The ISR now disables the pin interrupt on every level change; the rain task
    waits 20 ms, then re-arms interrupt + wake for the level opposite to the
    line's current level. A tip is counted when the magnet arrives (line LOW),
    with the existing 200 ms debounce. A pending change i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

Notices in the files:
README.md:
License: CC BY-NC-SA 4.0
